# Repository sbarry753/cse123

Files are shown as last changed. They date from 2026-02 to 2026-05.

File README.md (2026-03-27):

# GuSynth – Ultra-Low-Latency Polyphonic Guitar Synth Pedal
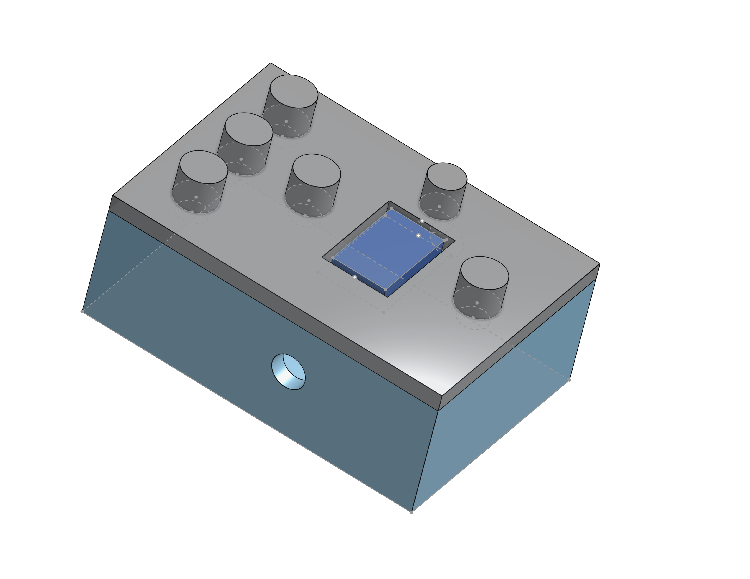
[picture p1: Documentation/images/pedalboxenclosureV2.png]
Aesthetic Prototype

GuSynth is a research + hardware project building a **real-time polyphonic guitar synth pedal** capable of transforming a guitar into other instruments with **ultra-low latency**.

The project combines:

- **Transient-guided neural note detection**
- **Polyphonic inference for guitar input**
- **Direct neural timbre transfer**
- **Embedded deployment on microcontroller hardware**
- **Analog tone shaping and post-processing**

The goal is a **standalone guitar pedal** that lets a guitarist play naturally while hearing the output as another instrument.

---

## Overview

Most pitch detection and guitar synthesis systems rely on longer analysis windows, which adds noticeable delay. GuSynth instead focuses on extracting useful information from the **earliest part of the note**, especially the pick attack, so the system can react quickly enough for live performance.

The project currently explores two connected ML stages:

1. **First neural network:** fast polyphonic note detection from very short windows
2. **Second neural network:** direct timbre transfer from guitar to another instrument

A harmonic LUT-based pipeline and analog processing stages support the overall system.

---

## Signal Path

This is the full signal path of the pedal, from instrument input through conversion, inference/synthesis, and output shaping.

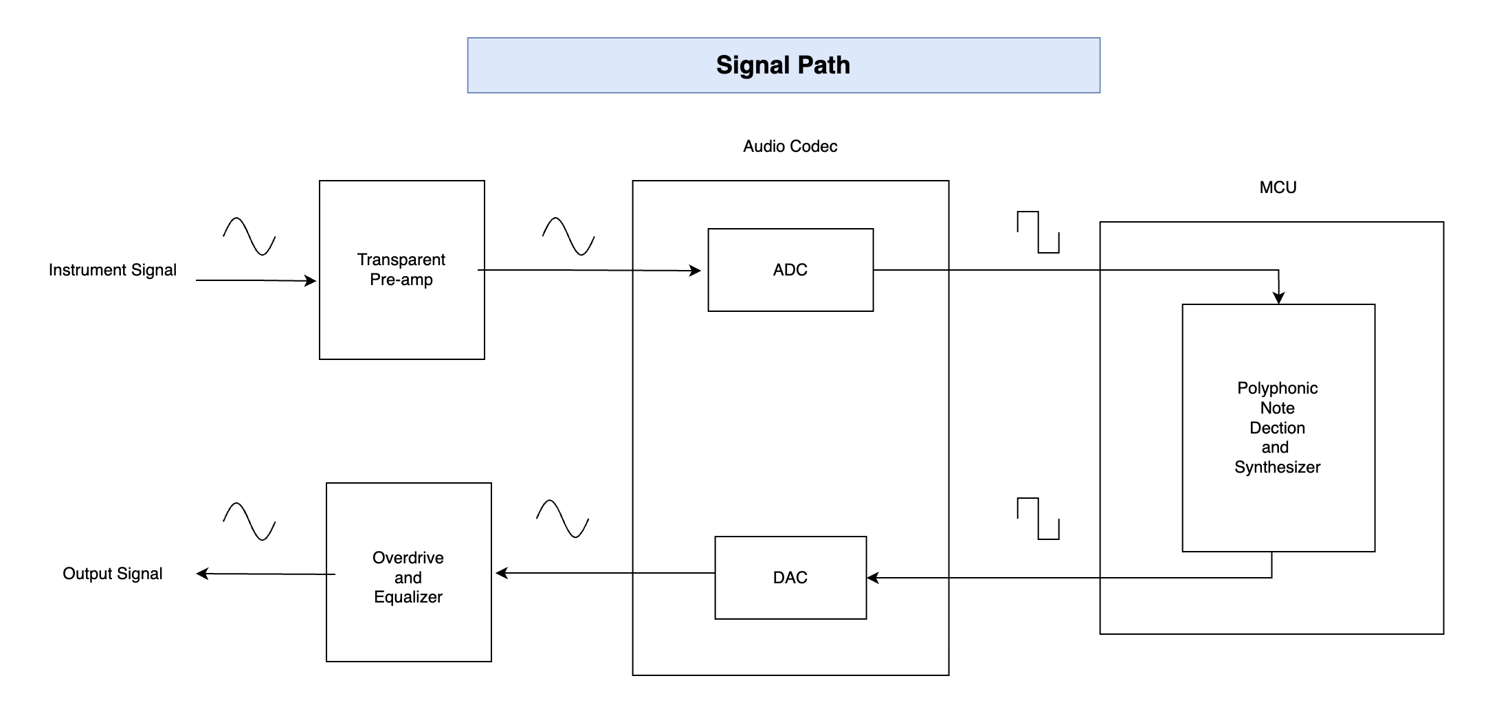
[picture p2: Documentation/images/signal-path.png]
Signal Path


---

## Overall Pedal / System Schematic

This diagram shows the higher-level pedal architecture and how the DSP / neural / synthesis stages connect together.

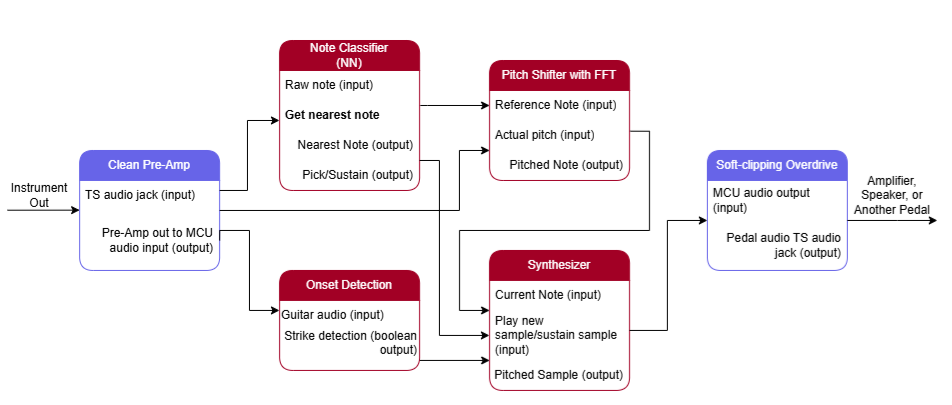
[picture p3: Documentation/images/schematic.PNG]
Overall Schematic


---

## 424 / Analog Circuit Reference

This section documents one of the analog reference directions used in the project for tone shaping / overdrive exploration.

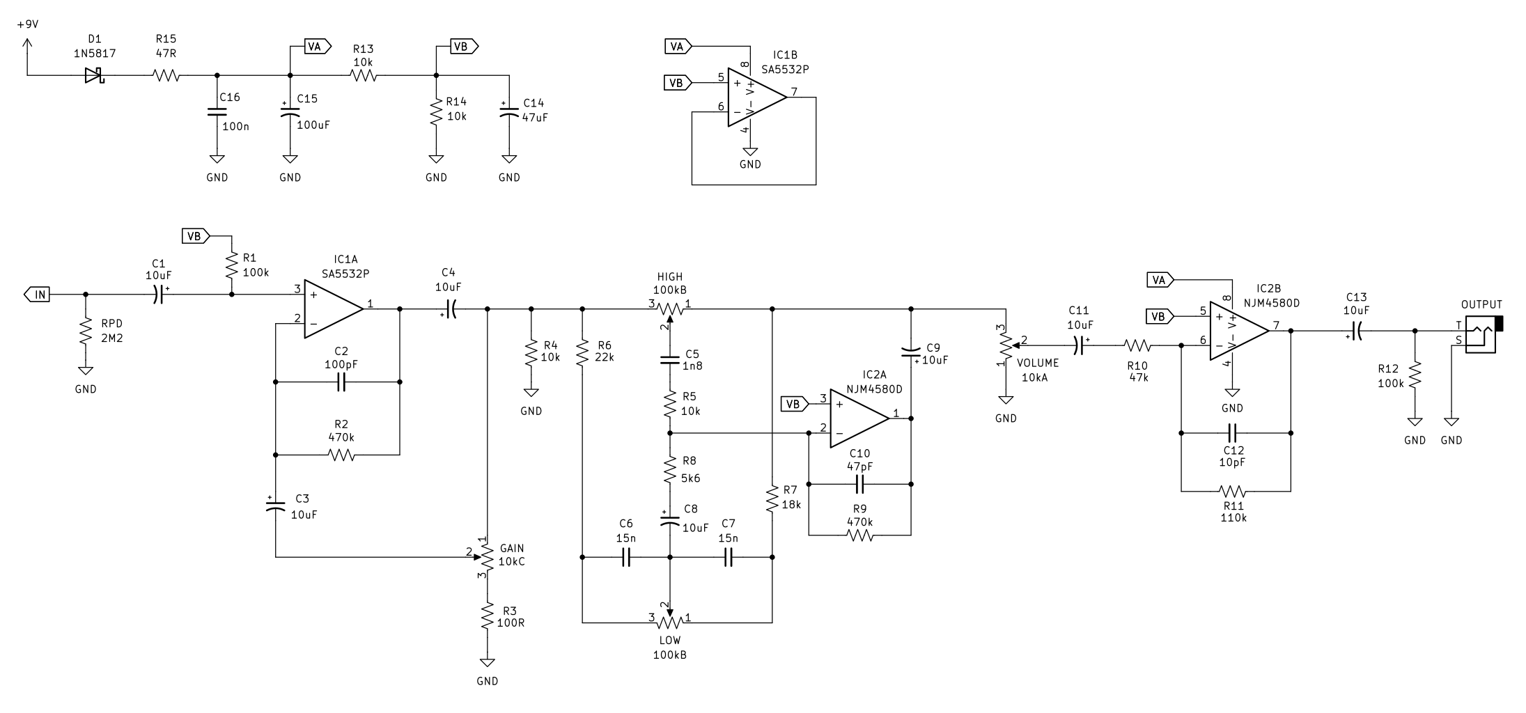
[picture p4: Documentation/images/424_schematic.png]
424 Schematic


---

## Core System Architecture

### 1. First Neural Network – Polyphonic Note Detection

The first model is designed to recognize notes from **very short guitar input windows**, with a strong focus on the **transient / pick attack** region.

It is intended to:

- detect note activity quickly
- work under polyphonic conditions
- provide a MIDI-style or note-based representation
- operate under strict latency constraints suitable for embedded systems

#### Audio Demo – First NN
First NN Input (https://www.youtube.com/watch?v=imzRmc-EM3o)

**After (first NN output / note-detection-driven result):**

First NN MIDI Out (https://www.youtube.com/watch?v=rfo7ya5QwPA)

### 2. Second Neural Network – Timbre Transfer

The second model takes guitar input and transforms it toward the sound of another instrument.

Current work is focused on **guitar → piano-style transfer**, with the long-term goal of supporting more instruments and cleaner real-time conversion.

It is intended to:

- preserve performance timing and expression
- reshape the raw guitar waveform into a target timbre
- run in a streaming low-latency pipeline
- support eventual embedded deployment

#### Video Demo – Second NN

Second NN Out (https://www.youtube.com/watch?v=lIXTaDWCdeU)

## Harmonic LUT Support Pipeline

Alongside the neural models, the project includes a harmonic fingerprint LUT approach used for analysis and refinement.

This system helps by:

- storing harmonic note templates
- comparing incoming spectra to expected note structure
- refining note hypotheses
- supporting interpretable DSP-guided analysis

Rather than treating the project as purely neural or purely classical DSP, GuSynth explores a **hybrid approach**.

---

## Embedded Hardware Target

The long-term target is a compact embedded pedal platform.

### Current embedded direction

- **Daisy Seed / Cortex-M7 class hardware**
- **48 kHz real-time audio**
- small-window streaming inference
- ADC / DAC audio pipeline
- analog front-end and output shaping

### Embedded constraints

- low total latency
- predictable real-time processing
- limited memory / compute budget
- models must be compact enough for sustained streaming

---

## Analog Processing

The pedal is not only digital / ML based. Analog stages are also important for:

- input conditioning
- gain staging
- distortion / overdrive
- EQ shaping
- reducing unpleasant artifacts in synthesized output

This is especially useful when blending guitar and synthetic instrument textures.

---

## Project Status

- ✅ First neural network prototype for transient-guided note detection
- ✅ Second neural network prototype for timbre transfer
- ✅ Harmonic LUT research pipeline
- ✅ System-level pedal architecture defined
- ⚠️ Embedded optimization still in progress
- ⚠️ More training data and refinement needed for cleaner output quality

---

## Repository Layout

- `Documentation/images/`  
  Diagrams, schematics, and system figures

- `Documentation/audio/`  
  WAV demos for model outputs

- `Documentation/video/`  
  Video demonstrations of the system

- `LUT - In Development/`  
  Harmonic fingerprint / template detection work

- `DAISY - In Development/`  
  Embedded hardware and firmware work

- `JUCE - In Development/`  
  Desktop or plugin prototyping

---

## Long-Term Goal

A standalone guitar pedal that:

- detects polyphonic playing with minimal delay
- converts guitar into the sound of other instruments
- runs on embedded hardware
- combines neural models, DSP, and analog circuitry
- remains responsive enough for real live performance

---

## Summary

GuSynth is a hybrid guitar-synthesis system exploring how far real-time note inference and timbre transfer can be pushed under embedded, performance-critical latency constraints.

It is not just a guitar effect — it is an attempt to turn the guitar into a **real-time expressive controller for other instruments**.

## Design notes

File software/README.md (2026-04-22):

#Software

This is where all software related files are going to be listed. Currently, I've moved mine but will be asking if we want to organize our directory through directories. Temporary organizational area for now.

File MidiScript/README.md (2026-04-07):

#MIDI to other instruments
Will be using a python script to convert .midi files into different .wav files with associated instruments.

Current conversion:
.midi to .wav Piano

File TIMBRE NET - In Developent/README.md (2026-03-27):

# DDSP Guitar → Piano (Live Timbre Transfer)

Real-time guitar-to-piano timbre transfer using DDSP (Differentiable Digital Signal Processing).
Designed for live performance with a **<12ms algorithmic latency budget**.

---

## Architecture

```
Guitar audio (256-sample frame, ~5.8ms)
  │
  ▼
Feature Encoder  [~2ms]
  • f0 via YIN autocorrelation
  • RMS loudness in dB
  • MFCC (20 coefficients)
  │
  ▼
MLP Decoder  [~0.5ms]
  • 4-layer MLP, 512 hidden units
  • Trained on YOUR paired data
  • Maps guitar features → piano synth params
  │
  ▼
Additive Synthesizer  [~2.5ms]
  • 64 harmonics + shaped noise
  • Phase-continuous across frames
  │
  ▼
Output audio  [~5.8ms buffer]

Total algorithmic latency: ~11ms ✓
```

---

## Setup

```bash
# 1. Create virtual environment
python -m venv venv
source venv/bin/activate   # Windows: venv\Scripts\activate

# 2. Install dependencies
pip install -r requirements.txt

# 3. On Windows, install ASIO for lowest driver latency:
#    Use ASIO4ALL or your interface's native ASIO driver
```

---

## Prepare Your Data

Organize your paired audio files like this:

```
data/
  guitar/
    phrase_001.wav
    phrase_002.wav
    ...
  piano/
    phrase_001.wav   ← same filename, time-aligned, same duration
    phrase_002.wav
    ...
```

**Requirements:**
- Any sample rate (will be resampled to 44100 Hz)
- WAV or FLAC format
- Files must be time-aligned (same musical content, same duration)
- More data = better results. 10+ minutes of paired audio recommended.

---

## Training

```bash
# Basic training (100 epochs, auto-detects GPU/MPS/CPU)
python train.py --data_dir ./data --epochs 100

# With custom settings
python train.py \
  --data_dir    ./data \
  --epochs      150 \
  --batch_size  128 \       # increase if GPU has memory
  --hidden_size 512 \
  --n_harmonics 64 \
  --lr          3e-4

# Resume from checkpoint
python train.py --data_dir ./data --resume ./checkpoints/epoch_0050.pt
```

Training outputs:
- `checkpoints/best_model.pt` — best checkpoint (use this)
- `checkpoints/model_scripted.pt` — TorchScript export for real-time
- `checkpoints/loss_curves.png` — training curves

**Expected training time:**
| Hardware | ~100 epochs |
|---|---|
| NVIDIA GPU | 20–60 min |
| Apple M-series  | 45–90 min |
| CPU only | 4–8 hours |

---

## Live Performance

```bash
# List available audio devices first
python realtime.py --model ./checkpoints/model_scripted.pt --list-devices

# Run live
python realtime.py --model ./checkpoints/model_scripted.pt

# With settings
python realtime.py \
  --model   ./checkpoints/model_scripted.pt \
  --wet     1.0 \     # 1.0 = full piano, 0.5 = 50/50 blend
  --volume  1.0 \
  --device  cuda      # or mps or cpu
```

**Keyboard controls (while running):**
| Key | Action |
|-----|---|
| `q` | Quit |
| `r` | Reset phase (fix phase artifacts between songs) |
| `+` | Increase volume |
| `-` | Decrease volume |
| `m` | Toggle dry/wet |

---

## Audio Interface Setup

For minimum total latency:

| OS | Driver | Target buffer |
|---|---|---|
| Windows | ASIO | 64–128 samples |
| macOS | CoreAudio | 64–128 samples |
| Linux | JACK | 64–128 samples |

Set `DEVICE_IN` / `DEVICE_OUT` at the top of `realtime.py` to your interface.

```python
# realtime.py — set these:
DEVICE_IN  = "Focusrite USB"     # your interface name (partial match works)
DEVICE_OUT = "Focusrite USB"
```

---

## Troubleshooting

**Model sounds bad / robotic:**
- Train longer (200+ epochs)
- Add more paired data (target >20 min)
- Check that guitar/piano files are actually time-aligned

**Audio dropouts:**
- Increase `BLOCKSIZE` to 512 (adds ~5.8ms latency but more stable)
- Use a dedicated audio interface (not built-in soundcard)
- Close other audio applications

**Phase artifacts between notes:**
- Press `r` to reset phase accumulator
- These are normal for notes with very different f0s

**Latency higher than expected:**
- Run `python realtime.py --model ... --list-devices` and check your interface's native ASIO latency
- Algorithmic latency is fixed at ~11ms; total latency = algorithmic + driver round-trip

---

## File Structure

```
ddsp_guitar2piano/
  model.py       — DDSP architecture (encoder, MLP, synth)
  dataset.py     — Paired audio dataset loader
  losses.py      — Multi-scale spectral loss
  train.py       — Training script
  realtime.py    — Live inference
  requirements.txt
```

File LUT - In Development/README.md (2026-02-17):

# Guitar → Harmonic Fingerprint LUT → Note / Chord Detection (Python prototype for a future JUCE VST)

This repo is a research-stage **template-based pitch / note identification** system for guitar audio.

It builds a **lookup table (LUT)** of *single-note templates* from labeled `.wav` recordings, then:

- **Monophonic:** classifies a single played note by scoring it against every note in the LUT (and every *take* of that note).
- **Polyphonic:** detects multiple notes (like a chord / strum) by fitting the spectrum as a **nonnegative mixture** of note templates (NNLS).

This is not waveform resynthesis. It’s **harmonic-structure matching** in the frequency domain.

---

## What the code actually does

### 1) Build step: multi-take templates per note

For each labeled note recording, the script:

1. Loads the WAV (stereo → mono)
2. Normalizes peak amplitude
3. Extracts a short analysis window (`--start`, `--dur`)
4. Optionally highpass filters (`--highpass`)
5. Computes an FFT magnitude spectrum (Hann by default)
6. For that note’s known fundamental `f0` (from MIDI + A4 reference), measures **harmonic peaks**

For harmonic index `h = 1..K`:

- Look near `h * f0` within `± tol_hz`
- Take the **max magnitude** in that band

That yields a harmonic amplitude vector:

`v = [A1, A2, ..., A_H]`

Then it normalizes it to remove loudness:

`fingerprint = v / sum(v)`

**But** the LUT doesn’t store just the fingerprint — each take stores extra spectral features too:

- harmonic peak frequencies (per harmonic)
- harmonic peak magnitudes (per harmonic)
- harmonic slope (linear fit of `log(amp)` vs harmonic index)
- inharmonicity (average relative deviation from ideal `k*f0`)
- spectral centroid
- spectral rolloff (85%)
- spectral flatness

So the LUT is **multi-take per note**, and each take is a richer “feature snapshot”.

## LUT format (`lut.json`)

Each note entry contains:

- `note`, `midi`, `f0_hz`
- analysis params used at build time (`k`, `tol_hz`, `window`, `analysis_start_sec`, `analysis_dur_sec`)
- `takes[]`: list of per-recording templates
- `source_wavs[]`: which wav files produced the takes

Example (simplified):

```json
{
  "note": "E3",
  "midi": 52,
  "f0_hz": 164.81,
  "k": 60,
  "tol_hz": 15.0,
  "window": "hann",
  "analysis_start_sec": 0.12,
  "analysis_dur_sec": 0.18,
  "takes": [
    {
      "fingerprint": [...],
      "peak_freqs": [...],
      "peak_amps": [...],
      "harm_slope": -0.42,
      "inharm": 0.0031,
      "centroid_hz": 812.4,
      "rolloff_hz": 2490.0,
      "flatness": 0.018
    }
  ],
  "source_wavs": ["samples/E3.wav", "samples/E3_lowstring.wav"]
}
````

---

## 2) Monophonic matching (single note)

Monophonic classification is **not**:

> “extract one fingerprint from the unknown and compare to stored fingerprints”

Instead the code does this:

For **each candidate note** in the LUT:

1. Compute that candidate note’s `f0` from its MIDI (and A4 ref)
2. Compute **live features assuming that f0** (fingerprint + other features)
3. Compare the live features against **every stored take** for that note

### Scoring: cosine similarity + feature penalties

* base similarity: `cosine(fingerprint_live, fingerprint_take)`
* penalties for:

  * inharmonicity difference
  * centroid ratio difference (log)
  * rolloff ratio difference (log)
  * harmonic slope difference
  * flatness difference

Weights are CLI tunable (`--w_inharm`, `--w_centroid`, etc.)

### Multi-take collapse (important)

A note has multiple takes → multiple scores.

Those take scores get collapsed into a **single note score** using:

* `--score_mode max` (default): best take wins
* `--score_mode mean`
* `--score_mode topk --topk N`: average of top N takes

Then the note with the highest final score is your winner.

So the classifier is basically:

> “try every note as if it were correct, see which assumption produces the best harmonic alignment + feature match.”

---

## 3) Polyphonic matching (chords / multi-string)

Polyphonic mode does **not** store chord templates.

It still uses the same **single-note LUT** — but match time changes.

### Step A — prune candidate notes (fast pre-pass)

It runs a cheap fingerprint cosine score per note and keeps only the top `--prune N` notes to limit NNLS size.

### Step B — build FFT-bin templates for each take

For each candidate note and each take:

* Convert the take fingerprint into a **template vector over FFT bins**
* “Paint” a small Gaussian bump at each harmonic frequency
* Weight bumps by the take’s fingerprint values
* Normalize template to unit norm

Optionally it adds detuned template variants (`--detune_cents`, default ±20c) to handle tuning drift.

You end up with a matrix:

`A = [template_1 template_2 ... template_M]`

### Step C — fit the live spectrum as a nonnegative mixture (NNLS)

It computes the live FFT magnitude `y` (optionally `log1p` with `--logmag`), normalizes it, then solves:

`min ||A x - y||  subject to x >= 0`

(using `scipy.optimize.nnls`)

### Step D — collapse templates → notes

Multiple templates correspond to the same note (multiple takes + detunes).

The code collapses them by taking the **max weight per note**, normalizes note strengths by the max, then outputs up to `--max_notes` above `--thresh`.

So polyphonic output is:

> “which notes have strong activations in the NNLS mixture.”

---

## Commands

### Build LUT from explicit labels

```bash
python wav_to_lut.py build --out lut.json --k 60 --tol 15 --start 0.12 --dur 0.18 \
  E3=samples/E3.wav E3=samples/E3_lowstring.wav
```

### Build LUT from a directory (note parsed from filename)

Supports filenames like:

* `E6.wav`
* `F#4_take2.wav`
* `Bb3-clean.wav`
* `E3_lowstring.wav`

```bash
python wav_to_lut.py build_dir --out lut.json --dir samples --k 60 --tol 15 --start 0.12 --dur 0.18
```

### Match monophonic

```bash
python wav_to_lut.py match --lut lut.json --wav unknown.wav --start 0.12 --dur 0.18 --plot
```

Useful knobs:

* `--score_mode max|mean|topk`
* `--w_inharm ...` etc (feature penalty weights)

### Match polyphonic (chord)

```bash
python wav_to_lut.py match_poly --lut lut.json --wav chord.wav --start 0.12 --dur 0.18 \
  --max_notes 6 --thresh 0.25 --prune 60 --detune_cents 20 --logmag --plot
```

---

## Notes / assumptions baked into the approach

* The system **does not do explicit f0 estimation** first.

  * It instead evaluates candidates by “assuming” their f0 and measuring harmonic alignment.
* Short windows matter: `--start` and `--dur` heavily affect stability (attack vs sustain).
* Polyphonic mode is spectrum-mixture-based (NNLS), so it works best when:

  * notes are reasonably harmonic
  * not too much distortion / noise
  * pruning keeps the NNLS problem manageable

---

## Roadmap (VST direction)

This Python code is meant to prototype:

* a note/chord detector that can run on short windows
* multi-take robustness (different strings / pickups / picking styles)
* template-mixture chord inference

A JUCE plugin version would likely need:

* streaming / overlap-add analysis windows
* faster solvers or approximations than full NNLS
* onset (“strike”) detection and tracking across frames

```
```

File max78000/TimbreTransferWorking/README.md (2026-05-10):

# TimbreTranser - MAX78000 FreeRTOS Audio Processing 

## Current functionality
- Audio passthrough, line in/out working on MAX78000FTHR
- FreeRTOS circular buffer integrated and tested
- Has audio processing and buffer demo running simultaneous
- !! NEURAL NETROK INTERFACE PENDING !!

## Hardwware Requirements
- MAX78000FTHR board
- (2) 3.5 mm auxiliary cables
- audio source and audio output device

## Setup development environment

### 1. Update MAX78000 debugger firmware 
 following the instructions [here](https://github.com/analogdevicesinc/MaximAI_Documentation/blob/main/MAX78000_Feather/README.md)

### 2. Install MaxiSDK
- [Install MaximSDK](https://analogdevicesinc.github.io/msdk/USERGUIDE/#installation)
- [setup with Visual Studio Code](https://analogdevicesinc.github.io/msdk/USERGUIDE/#getting-started-with-visual-studio-code)
- Install [Serial Monitor](https://marketplace.visualstudio.com/items?itemName=ms-vscode.vscode-serial-monitor) extension

### 3. **CRITICAL: Replace the MAX9867 driver**
    - Backup `max9867.c/h` in `Libraries/MiscDrivers/CODEC` in the MaximSDK installation folder.
    - Replace `max9867.c/h` with the versions in the `driver` folder contained within *this* folder. Each time we update the driver code, this process must be repeated. (Probably we want to not perform this process later on)

### 4. Build and Flash 
Connect MAX78000FTHR board, and monitor it using the Serial Monitor extension; build and flash using [this](https://analogdevicesinc.github.io/msdk/USERGUIDE/#visual-studio-code) guide.

## Testing Audio Passthrough
1. Connect audio source (computer/phone) → J5 (line-in jack)
2. Connect speaker/headphones → J7 (line-out jack)
3. Play audio - you should hear it through the speaker
4. LED2 should blink at ~1Hz (indicates DMA running)

## Circular Buffer
The project includes a FreeRTOS-compatible circular buffer (`buffer.c`, `buffer.h`) ported from POSIX semaphores written by David Harrison. Demo tasks (producer/consumer) run alongside audio passthrough to verify functionality.
 
## SDK Bugs
1. **Codec driver broken** - Fixed by patched driver (see setup step 3)
2. **I2C not initialized** - Driver assumes I2C already initialized ([Issue #762](https://github.com/analogdevicesinc/msdk/issues/762))

## Debugging in the command line
To step through the program in GDB, follow this sequence:
- Connect the MAX78000FTHR board, and monitor it using the Serial Monitor extension.
- Open a terminal window and enter *this* directory.
- Run `make clean`, then `make all`, then `make flash-hold`.
- Open a new terminal window, without closing the previous one, and enter this directory. In the new terminal window, run `make gdb-debug`. You should now be in GDB, with the program paused at `main()`. [Reference for GDB commands](https://visualgdb.com/gdbreference/commands/)

## Contributors
- Zion - Initial audio passthrough setup
- Yasmeen - Cicular buffer port, SDK bugs, documentation

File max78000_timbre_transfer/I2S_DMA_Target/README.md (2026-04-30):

## Current functionality
At the moment, the program passes audio straight through without affecting it.

## Setup development environment
1. Update MAX78000 debugger firmware by following the instructions [here](https://github.com/analogdevicesinc/MaximAI_Documentation/blob/main/MAX78000_Feather/README.md)
2. [Install MaximSDK](https://analogdevicesinc.github.io/msdk/USERGUIDE/#installation), and [setup with Visual Studio Code](https://analogdevicesinc.github.io/msdk/USERGUIDE/#getting-started-with-visual-studio-code)
3. Install [Serial Monitor](https://marketplace.visualstudio.com/items?itemName=ms-vscode.vscode-serial-monitor) extension
4. Replace the MAX9867 driver
    - Backup `max9867.c/h` in `Libraries/MiscDrivers/CODEC` in the MaximSDK installation folder.
    - Replace `max9867.c/h` with the versions in the `driver` folder contained within *this* folder. Each time we update the driver code, this process must be repeated. (Probably we want to not perform this process later on)
5. Connect MAX78000FTHR board, and monitor it using the Serial Monitor extension; build and flash using [this](https://analogdevicesinc.github.io/msdk/USERGUIDE/#visual-studio-code) guide.

## Debugging in the command line
To step through the program in GDB, follow this sequence:
- Connect the MAX78000FTHR board, and monitor it using the Serial Monitor extension.
- Open a terminal window and enter *this* directory.
- Run `make clean`, then `make all`, then `make flash-hold`.
- Open a new terminal window, without closing the previous one, and enter this directory. In the new terminal window, run `make debug`. You should now be in GDB, with the program paused at `main()`. [Reference for GDB commands](https://visualgdb.com/gdbreference/commands/)

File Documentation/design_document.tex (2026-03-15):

\documentclass[12pt]{article}

\usepackage{hyperref}
\usepackage{amsmath}
\usepackage{enumitem}
\usepackage{graphicx}
\usepackage{eso-pic}
\usepackage{float}

\title{
\textbf{GuSynth: The Polyphonic Guitar Synth Pedal}\\
\vspace{0.5em}
\large System Overview and Design Description}

\author{Team 2: Kai, Zion, Barry, Nick, Yasmeen, Aaryan}

\begin{document}

\AddToShipoutPictureBG*{%
    \AtPageLowerLeft{%
        \hspace{1cm}% left margin from edge
        \raisebox{1cm}{% height from bottom
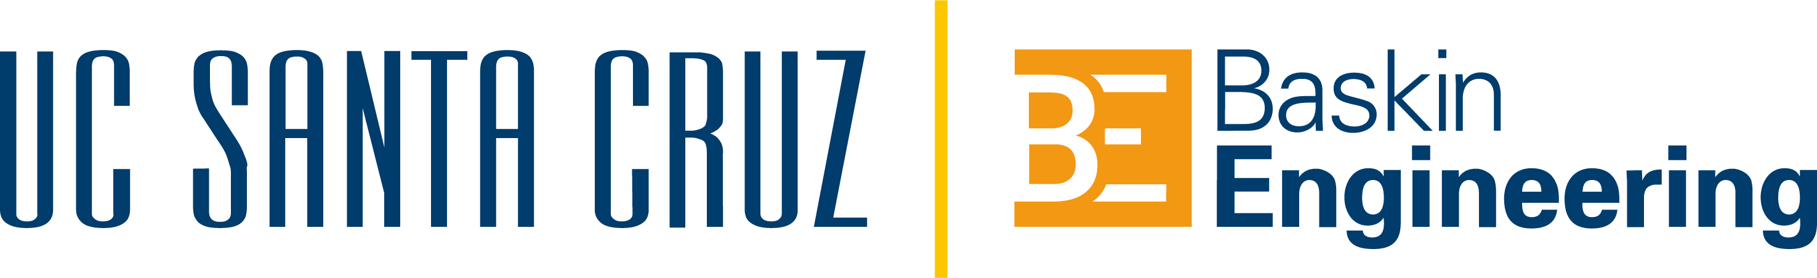
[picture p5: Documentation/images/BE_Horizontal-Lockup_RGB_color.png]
            
        }
    }
}
\maketitle
\thispagestyle{empty}

\newpage
\tableofcontents  
\newpage

\newpage

\section*{Executive Summary}
This project explores the design of a guitar pedal that transforms traditional guitar sounds into tones resembling other instruments or synthesizers. Using a mixture of both analog and digital effects, this system aims to form a physical guitar pedal that combines multiple systems to achieve this. One of the biggest constraints to consider is latency; the system should produce the output sound fast enough to feel immediate during play.

\section{Introduction}
\subsection{Need and Goal Statements}
\textbf{Need Statement:} Guitarists want to be able to create the sound of another instrument without having to remove their guitar during live performance, or learn a new instrument.\\
\textbf{Goal Statement:} Allow guitarists to play the sounds of different instruments with their guitar in real time.

%old statements
%\textbf{Need Statement:} Existing guitar-controlled synthesizers cannot detect and play more than one note at once, which limits the expressiveness of the guitar.\\
%\textbf{Goal Statement:} Design a polyphonic guitar synth pedal that is intuitive for guitarists and suitable for live performance. 
%(ALLOW MUSICIANS TO PLAY DIFFERENT SOUNDS WITHOUT SWITCHING INSTRUMENTS IN REAL TIME (<10 ms))

\subsection{Design Objectives} %(Polyphonic is the objective/solution)

\begin{enumerate}[label=(\alph*)]

    \item \textbf{Polyphonic Note Detection} \\
    The guitar is inherently polyphonic, but accurate and general-purpose polyphonic note detection is still an open challenge. In order to provide accurate polyphonic note detection, the device needs to accurately infer the number of distinct notes played in a guitar chord, and their individual pitches.

    \item \textbf{Low Latency} \\
    A latency of $10\,\text{ms}$ is targeted, to facilitate an intuitive and enjoyable user experience. The player should not perceive any delay between playing a note and hearing the synthesized sound through their amplifier. This strict latency requirement drives many of our architectural and algorithmic decisions.

    \item \textbf{Form factor} \\
    The device must fit comfortably onto a guitar pedal board, and conform to the design language of existing guitar effects pedals. Additionally, the device must accept 9V DC power from a coaxial jack (5.5mm x 2.1mm, center-negative), standard for guitar pedals.

%    Note: By existing design language, I mean:\\
%    - Input goes from right to left \\
%    - Power jack is facing away from user \\
%    - All user controls located on the upward-face of the pedal\\
%    - Bypass footswitch is located on lower portion of the interface\\
%    - Knobs and parameter controls are located on the upper portion of the interface\\
%   Where should this information go?

\end{enumerate}

%\subsection{Existing Products}
% other guitar synth pedals (BOSS GT-3, 1997, has a monophonic guitar synth effect)
% melodyne and other software solutions (polyphonic detection)

\subsection{Target Audience (Personas)}
\begin{enumerate}[label=(\alph*)]
  \item \textbf{Bedroom Guitarist} \\
  A casual hobbyist looking to expand their creative palette without investing in additional instruments. They want expressive, unique sounds from gear they already own, in a package that is easy to set up and experiment with.
  \item \textbf{Recording Studio} \\
  A producer or session musician seeking precise, repeatable tones for tracking  and layering. They value low noise, consistent output, and seamless integration  into an existing signal chain or Digital Audio Workstation (DAW) workflow.
  \item \textbf{Live Performer} \\
  A performing musician who needs reliable, low-latency response under stage  conditions. They prioritize a rugged form factor, intuitive controls that can  be adjusted on the fly, and a sound that cuts through in a live mix.

\end{enumerate}

\clearpage
\section{Design of the Pedal}

\subsection*{Aesthetic Prototype}
\begin{figure}[H]
    \centering
    
    \caption{Aesthetic Prototype}
    \label{fig:aesthetic-prototype}
\end{figure}

\subsection*{High-Level Block Diagrams}

\begin{figure}[H]
    \centering
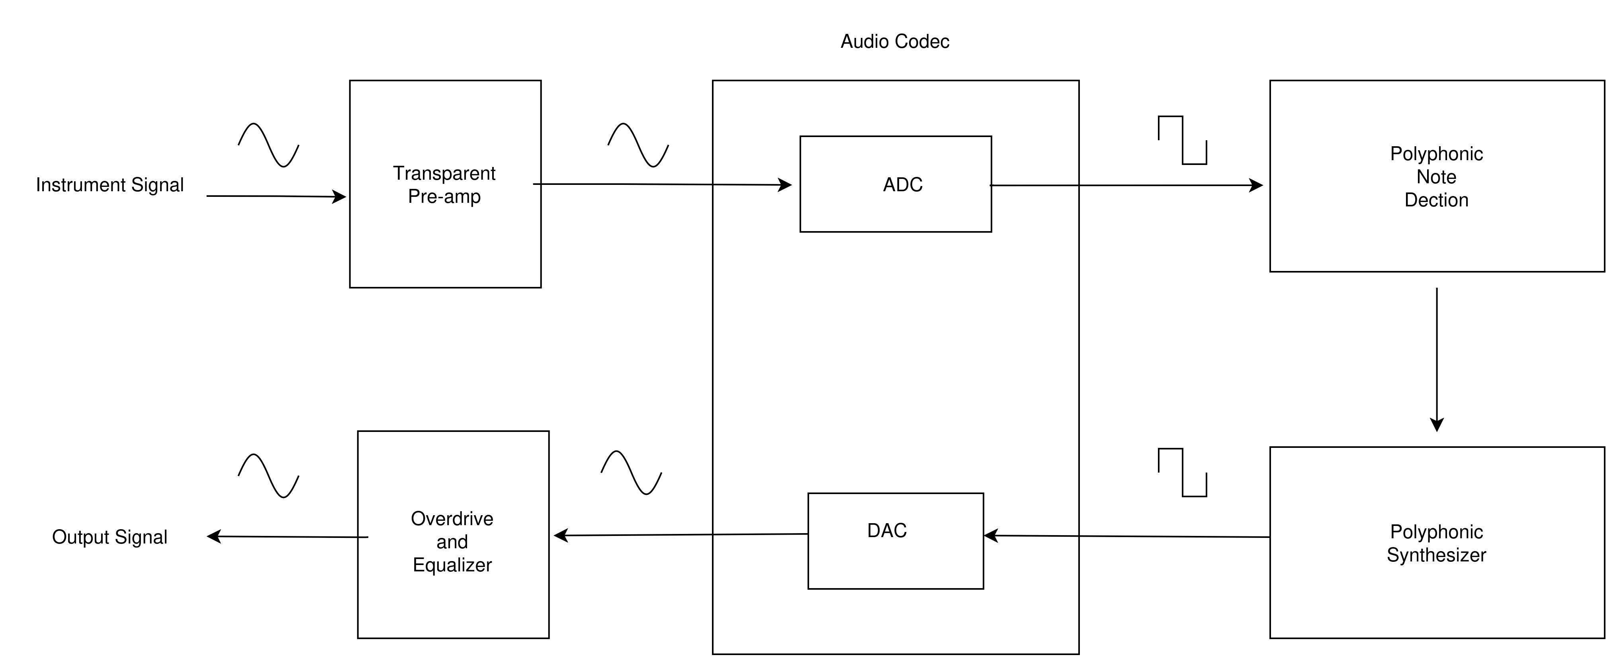
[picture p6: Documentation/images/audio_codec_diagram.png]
    
    \caption{Signal Path }
    \label{fig:block-diagram-signal}
\end{figure}

\begin{figure}[H]
    \centering
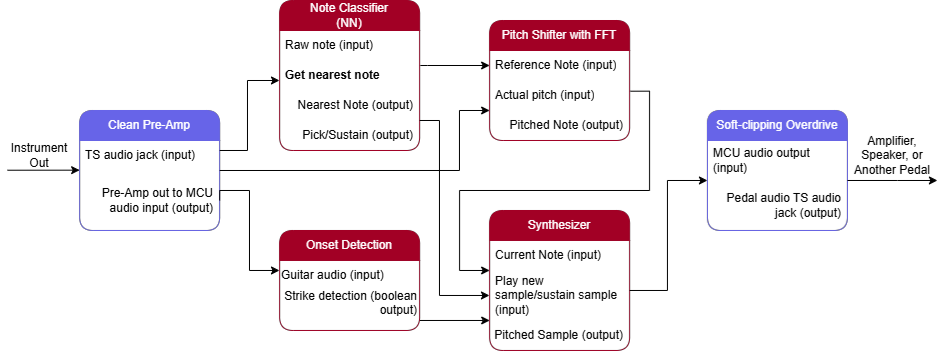
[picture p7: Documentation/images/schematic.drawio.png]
    
    \caption{Pedal Block Diagram}
    \label{fig:block-diagram}
\end{figure}

\subsection{Software System}

The software pipeline begins when the micro controller receives a digitized audio  stream from the analog-to-digital converter (ADC). The incoming samples are written into a ring buffer, which alternates between two fixed-size memory regions.  While one buffer accumulates new input samples, the other is made available for processing. This scheme ensures continuous, uninterrupted audio throughput and is  fundamental to meeting the low-latency requirements of the system.

Once a buffer is released for processing, the audio data is passed into a neural network inference pipeline. Rather than performing an explicit frequency decomposition,  the network approximates the pitch and onset characteristics of the incoming signal  directly, identifying which notes are present in the input. The microcontroller then uses these predictions to drive a synthesis engine, which generates an output waveform to produce the desired sound effect. The synthesized digital signal is subsequently converted back to an analog output via the digital-to-analog converter (DAC), where it is routed into the analog output stage.

\subsubsection{Neural Network}
A neural network is used to perform rapid note detection from the incoming guitar signal. Traditional pitch detection methods require observing multiple waveform periods, which introduces latency that is too high for a real-time pedal. Instead, a small neural network analyzes short audio windows (approximately 5–8 ms) to infer note identity directly from the signal’s transient and early harmonic content.
The model is implemented as a lightweight 1-D convolutional neural network designed for embedded inference. It predicts note class and onset information from each audio window, allowing the system to detect new notes almost immediately after a string is picked. These predictions provide an early estimate of the notes present in the signal, which can then be refined by later stages of the detection pipeline.

The trained network is exported to C and compiled directly into the microcontroller firmware, allowing it to run efficiently within the real-time audio processing loop. This approach enables low-latency note detection suitable for live instrument synthesis.
\subsubsection{Synthesizer}

The microcontroller supports any mathematically programmable audio effect, with the available effects limited only by the memory constraints of the hardware. Each effect is implemented as an independent processing function that transforms the incoming audio sample using a defined algorithm. The baseline implementation includes fuzz and distortion, which shape the waveform through non-linear gain functions. The firmware architecture allows developers to implement additional effects during the build phase, provided they can be expressed as a deterministic sample-by-sample transformation and fit within the available memory budget of the microcontroller. Once the effect is applied, the processed signal is passed through an automatic gain control (AGC) stage, which normalizes the output volume before the signal is forwarded to the DAC.

\subsection{Embedded Platform}
The embedded system bridges the digital and analog components of the pedal. The guitar signal from the transparent preamp enters an audio codec. The audio codec converts the analog waveform into discrete digital samples via an Analog-to-Digital converter. Then, these samples are transferred to the microcontroller using the Serial Audio Interface (SAI). Transferring the audio samples to the MCU is performed using Direct Memory Access (DMA). DMA places data into the MCU's RAM without CPU intervention, removing the need for the CPU to constantly poll and waste cycles. Once the samples are in RAM, the polyphonic and algorithms process the audio in software. When the signal has finished processing, it is sent back to the audio codec via DMA, then the Digital-to-Audio converter (DAC), and finally into the analog stage.

Audio is processed in small blocks to maintain our $<10\,\text{ms}$ latency target. Each stage in this pipeline is designed with real-time performance in mind. Furthermore, the pedal will feature a digital OLED screen. The screen indicates the current selected synth type. To change the currently selected synth and cycle through all options, a button is used. The OLED screen and the microcontroller communicate via the I2C protocol.

\subsection{Analog Circuits}
The pedal contains two primary analog circuits.

\subsubsection*{Transparent Preamp}
The preamp boosts the guitar signal to line level before feeding it into the ADC of the microcontroller. It is designed to be transparent so that the note detection neural network, which is trained on DI guitar audio, can work effectively.

\subsubsection*{Overdrive Circuit}

\begin{figure}[H]
    \centering
    
    \caption{Overdrive and Equalizer Circuit Schematic}
    \label{fig:424-schematic}
\end{figure}

The DAC of the microcontroller then feeds the synthesized audio signal into the second analog stage. This second stage is an overdrive circuit with EQ controls. This allows us to shape the tone and gain of the synth in the analog domain before sending it to the user’s amplifier, pedal chain, or other compatible equipment. This stage also provides master volume control.

Our current prototype draws inspiration from the Tascam 424 preamp architecture and a simple Wampler-style overdrive circuit. 

\subsection{Physical Construction}
The pedal enclosure follows the mechanical design conventions of standard guitar effects pedals in order to integrate easily into existing pedalboards.
The user interface consists of two rotary knobs, a push button for switching between synthesizer modes, and a foot-actuated bypass switch. The knobs are panel-mounted potentiometers connected to the microcontroller’s ADC inputs, allowing the user to adjust effect intensity and select different synthesis modes. The footswitch is designed for repeated mechanical stress during live performance.
A small OLED display is mounted on the top panel of the enclosure to provide feedback about the currently selected synthesizer mode. This allows the user to quickly verify which sound is active without relying solely on knob positions.
\section{Evaluation}
Evaluation of the pedal focuses on verifying that the system meets its functional requirements and performance goals. The evaluation process examines both hardware reliability and system performance, including power behavior, mechanical durability, and audio latency.

Testing procedures were designed to validate the pedal under realistic usage conditions similar to those encountered by musicians during rehearsal, recording, and live performance. These tests ensure that the device behaves predictably when subjected to typical physical interaction.

The evaluation phase also helps identify potential areas for improvement in the design, such as latency optimization, mechanical durability, or signal quality. By systematically verifying the core requirements of the system, we can properly determine that our prototype reaches our desired goals.
\subsection{Functional Prototype}

% Tests verify whether the design objectives are met
% Need to test every configuration
\subsection{Testing} 

\subsubsection{Power on}

\textit{Summary: The pedal should only power on when an input cable is connected. The power LED should only illuminate when the effect is not bypassed.}\\

Procedure:
\begin{enumerate}
    \item Initially, the pedal has no power or signal connections.
    \item Connect the pedal to a 9V DC, center-negative power supply.
    \item \textbf{Check}: The power LED should be off.
    \item Press the bypass switch.
    \item \textbf{Check}: The power LED should be off.
    \item Connect the output cable from the pedal to a powered-on guitar amplifier.
    \item \textbf{Check}: The power LED should be off.
    \item Connect the input cable.
    \item If the power LED is off, press the bypass switch.
    \item \textbf{Check}: The power LED should be illuminated, and the effect should be active.
    \item Disconnect the input cable.
    \item \textbf{Check}: The power LED should be off.
    \item Reconnect the input cable.
    \item \textbf{Check}: The power LED should be illuminated and the effect should be active.
    \item Press the bypass switch.
    \item \textbf{Check}: The power LED should be off and the unaltered guitar signal is passed to the amplifier.
\end{enumerate}
\subsubsection{Physical construction}

\textit{Summary: The pedal should support the full weight of an adult (max. 220lbs).}\\

Procedure:
\begin{enumerate}
    \item Place a flat, broad wooden platform onto the bypass switch.
    \item Load the platform with 220lbs of weight, taking care that it is supported entirely by the bypass switch.
    \item Remove the load, then the platform.
    \item \textbf{Check:} The pedal is not damaged or deformed in any way.
    \item \textbf{Check:} The bypass switch still toggles the effect.
\end{enumerate}

\subsubsection{Latency}
% This should be made more specific, and may need an illustration, but this is the idea.
\textit{Summary: The pedal must have a latency under 10ms.}\\\\
Equipment:
\begin{itemize}
    \item Oscilloscope
    \item Function generator
    \item 1/4" TS instrument cable x 2
    \item 1/4" TS jack, female x 2
\end{itemize}
Procedure:
\begin{enumerate}
    \item Configure the function generator to send a 440Hz, 100mVpp sinusoidal wave into a 1/4" TS jack.
    \item Channel 1 of the oscilloscope reads the output of the function generator from the 1/4" TS jack.
    \item A 1/4" instrument cable connects the output of the function generator to the input of the pedal.
    \item A 1/4" instrument cable connects the output of the pedal to the other 1/4" TS jack.
    \item Channel 2 of the oscilloscope reads the output of the pedal from the 1/4" TS jack.
    \item Configure the oscilloscope to simultaneously display Channel 1 and 2, with the same time scale.
    \item \textbf{Check:} Use cursors or other utilities on the oscilloscope to determine the phase shift of the waveform introduced by the pedal. If the pedal introduces a 10ms delay or higher, this test is failed.
\end{enumerate}

%------------------------------------------------
\section*{Appendix 1: Problem Formulation}
\subsection*{Conceptualizations}
The core concept of this project is a guitar pedal capable of transforming the sound of a guitar into the timbre of other instruments or synthesized sounds in real time. Unlike traditional guitar effects pedals that modify the waveform of the input signal directly, this system attempts to infer the musical notes being played and then generate a new signal based on those notes.

The final concept combines multiple techniques. A neural network is used to estimate note activity from very short audio windows, while a digital synthesis engine generates the output sound. Analog circuitry is used both before and after the digital processing stage to condition the signal and shape the tone.

This hybrid approach allows the system to maintain low latency while still enabling expressive sound transformations.
\subsection*{Brainstorming}
During the brainstorming phase, the team explored multiple possible features and system architectures for the pedal. Ideas included:

\begin{itemize}
\item Real-time instrument emulation (piano, strings, brass)
\item Guitar-to-MIDI conversion
\item Polyphonic pitch tracking
\item Neural network–based note detection
\item Analog distortion and tone shaping
\item Built-in effects such as fuzz or modulation
\item Visual feedback through an OLED display
\item Adjustable synthesis parameters through knobs
\item Pedalboard-compatible enclosure design
\end{itemize}

\subsection*{Decision Tables}
During the design process, several alternative approaches were evaluated. Table~\ref{tab:decision} summarizes the major design choices and the reasoning behind the final selections.

\begin{table}[H]
\centering
\resizebox{\textwidth}{!}{
\begin{tabular}{|l|l|l|l|l|}
\hline
Design Component & Option A & Option B & Option C & Selected Approach \\ \hline
Pitch Detection & FFT peak detection & Autocorrelation/YIN & Neural network & Neural network \\ \hline
Signal Processing & Fully analog & Hybrid analog/digital & Fully digital & Hybrid analog/digital \\ \hline
Synthesis Method & Sample playback & DSP synthesis & External MIDI synth & DSP synthesis \\ \hline
Display Interface & No display & LED indicators & OLED display & OLED display \\ \hline
Control Interface & Buttons only & Knobs only & Knobs + button & Knobs + button \\ \hline
\end{tabular}
}
\caption{Design decision comparison}
\label{tab:decision}
\end{table}
The neural network approach was selected because it offers the potential for lower latency detection compared to traditional pitch detection methods, particularly when analyzing short windows of audio.

\subsection*{Morphological Charts}
A morphological chart was used to explore combinations of possible subsystem implementations.

\begin{table}[H]
\centering
\begin{tabular}{|l|l|l|l|l|}
\hline
Component & A & B & C & Selected \\ \hline
Pitch Detect & FFT & YIN & NN & NN \\ \hline
Processing & Analog & Hybrid & Digital & Hybrid \\ \hline
Synthesis & Samples & DSP & MIDI & DSP \\ \hline
Display & None & LEDs & OLED & OLED \\ \hline
Controls & Buttons & Knobs & Knobs+Btn & Knobs+Btn \\ \hline
\end{tabular}
\caption{Design decision comparison}
\end{table}
%------------------------------------------------

\clearpage
\section*{Appendix 2: Planning}

\subsection*{Basic Plan / Gantt Chart}

\begin{figure}[H]
    \centering
    
    \caption{Winter Quarter Gantt Chart}
    \label{fig:wintergantt}
\end{figure}

\subsection*{Division of labor during prototyping phase}
This graph is a screenshot from our GitHub Project of tasks assigned, in progress, on the backlog and completed grouped by our team members. The pink columns are what you're looking for, they are the completed tasks done by each member. 
Kai: Kaimul24
Nick: NickWeaver02
Aaryan: aaryanhlawat
Barry: sbarry753
Yasmeen: yamaniiiii
Zion: zion-silveyra
\begin{figure}[H]
    \centering
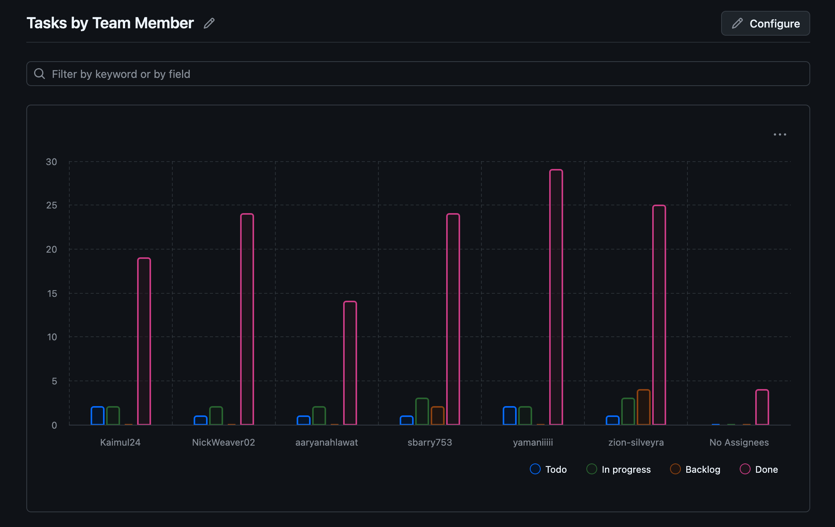
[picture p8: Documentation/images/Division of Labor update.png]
    
    \caption{Division of Labor}
    \label{fig:labor}
\end{figure}

\subsection*{Collaboration ( did you use tools beyond your repository? how did you assign tasks? )}
We use a GitHub Project that ties into our repository. There are a lot of tasks that are not necessarily able to be uploaded to a repository so we use the GitHub Project to track our members' progress on those.  

At the beginning, we used a Google Drive folder for collaboration on written assignments. We have since ported those documents to our repository, but we still use the Google Drive folder to organize collaborative files, like the Draw.io file for the overhead schematic, before pushing them to GitHub.

This design document is made with Overleaf, which is an online LaTeX editor that has collaborative functions like Google Docs. We then upload this work to our GitHub repository.

We communicate daily using our Discord server and have our discussions separated simply into a few channels: general, links and images, analog, embedded, and software. This helps us keep our communication organized and share our progress and findings.

We use Onshape, a collaborative cloud based CAD suite, to create our aesthetic prototype. There is a revision system included in Onshape. Our designs are then pushed to our GitHub repository.

We use Canva for making our demo slides. Canva is a collaborative cloud based graphic design suite that is easy to use. We push updated versions of our slides to our GitHub repository.

%------------------------------------------------
\section*{Appendix 3: Test Plan and Results}

\subsection*{Analog Effect Behavior}
We set out to make a distortion effect for the analog effect portion of the pedal. In order to test whether our distortion effect actually distorts the guitar signal we hooked up our circuit to an oscilloscope and a signal generator. The signal generator is generating a sine wave at 440Hz at 90mVpp to provide a clean A note from a guitar, the yellow wave. We're looking for the guitar's signal to clip at the peaks of the wave. The blue wave is the output from the distortion effect and it is clearly clipping the peaks of the signal and turning the guitar's sine wave into almost a pure square wave. This is the behavior of a hard clipping fuzz distortion effect which is the exact effect tested here.
\begin{figure}[H]
    \centering
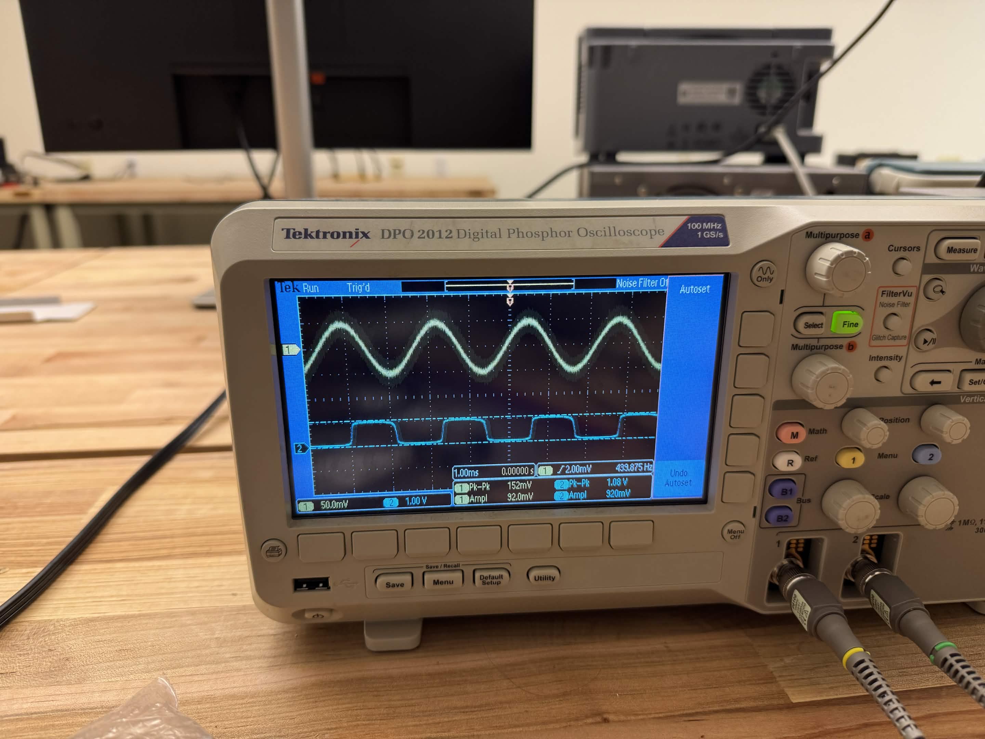
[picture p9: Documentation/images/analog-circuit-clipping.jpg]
    
    \caption{Clipping Distortion of an Analog Signal}
    \label{fig:analogclippig}
\end{figure}

\subsection*{Daisy Seed Benchmarking}
To get a sense of the processing power of the Daisy Seed (ARM Cortex M7 CPU), we decided to run a series of benchmarks. We first ran benchmarks for standard audio effects, similar to those found in the DaisyExamples repository provided by Electrosmith. In those tests, we determined that the actual audio effects did not result in any significant CPU load within a time budget. Then, we decided to stress test the MCU with matrix multiplication. This was an important benchmark to run because it is computationally demanding and relates directly to neural network inference performance. However, we found the MCU performed relatively poor in matrix multiplication, unaligned with real-time inference in mind. The MCU hit its maximum CPU load quickly during matrix multiplication, despite optimizations.

More detailed benchmarking information can be found in the \textit{Benchmarking} directory of our repository.

\begin{figure}[H]
    \centering
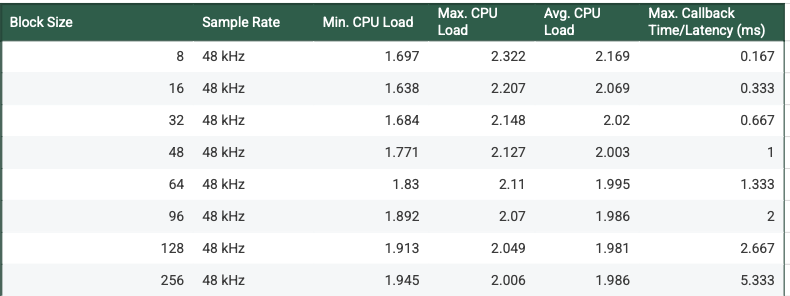
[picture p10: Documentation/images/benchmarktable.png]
    
    \caption{Benchmark Table (Passthrough)}
    \label{fig:benchmarkchart}
\end{figure}

\begin{figure}
    \centering
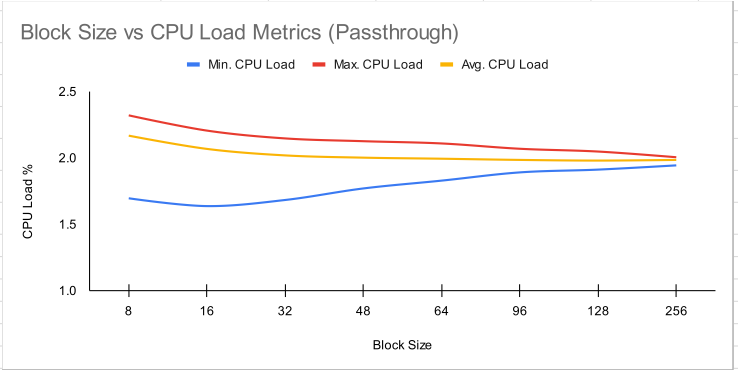
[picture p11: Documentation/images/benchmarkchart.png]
    
    \caption{Benchmark Chart (Passthrough)}
    \label{fig:benchmarkchart}
\end{figure}

%------------------------------------------------
\section*{Appendix 4: Review}

\subsection*{Kai}
For this quarter, I believe we should be proud of what we have accomplished this far. As someone who has had no prior experience with guitars or music creation, this project has allowed me to learn something new. I also really enjoy the direction this project is taking. Running neural network inference on a microcontroller has been something I've been wanting to do for a while, I just didn't come up with a project I really liked. 

If I were to start this project over again, I would like to have started with a more powerful microcontroller. While the Daisy Seed is meant for high-quality audio systems, it doesn't have nearly enough processing power for real-time neural network inference as our project currently stands. Running the matrix multiplications benchmarks revealed the computational limitations of the Daisy Seed. The Teensy 4.0 we were considering (but shipping was delayed) using is faster, but it still uses the same CPU. Early next quarter, we can still try to optimize inference on the Daisy Seed (continue working with tflite micro), but it may be worthwhile to consider more powerful MCU options.

\subsection*{Zion}
I'm very happy with the progress we've made this quarter. Initially, I had pitched the idea of making a digital multieffects unit for guitar, but the project has been going in a far more interesting direction since we've adjusted our goal. I've been able to use this project as an opportunity to learn about audio circuits, which has been wonderful. I am excited that next quarter we will try and design a PCB for our project.

If I were to start this project over again, I would spend more time researching relevant papers and existing tools, and sharing findings with the team. I found an optimizing compiler for neural networks targeting STM32 microcontrollers (STEDGEAI-CUBEAI) rather late in the quarter. Had I found this earlier, our team could have saved a lot of effort. I would also have spent more time documenting the work I had completed. Most of the work I had done researching analog effect circuits, constructing the overdrive/EQ circuit, and learning to use KiCad appears invisible in our repository. 

\subsection*{Barry}
What went well was that I learned a lot about guitar pedal design which is something that I've been wanting to do for many years now. We figured out which type of effect we wanted for the analog circuit pretty quickly and ordered parts immediately. The Daisy Seed microcontroller we were planning to use arrived very quickly and we found out that our backup, the Teensy 4.0 coming from Adafruit, took weeks for parts to arrive. I discovered a local guitar shop that stocks a few very common pedal parts too. Finding DIY pedal hobbyist sites online was very easy. There are a lot of passionate people out there that I'm thankful for their guidance and their fast shipping. Zion has lent me a guitar so I've been trying to learn guitar so that we can easily test our pedal design. Half our team has a guitar and the other half has a Daisy Seed/Pod so we all can test our designs. We frequently meet up in person to complete work and I enjoy every moment of it. I've also learned to use Github Project and find it very useful for keeping track of all our tasks and looking at the Roadmap. Making the CAD model for our aesthetic prototype was a breeze because of my previous CAD experience but I did have to learn a new CAD suite, Onshape.

Our team formed at the last week that we could form teams and we took a while to decide on a project to move forward with. And then it took us a while to figure out what we wanted the pedal to actually do. I wish I had joined this team earlier so that we could have made these decisions earlier. I still think that we've done a bang-up job despite our shorter timeline for this quarter. I also wished that I had ordered a bunch more parts for different types of analog circuits. We were lucky that I had a bunch of parts already at my disposal from previous personal projects. But I didn't have a bunch of film capacitors or large logarithmic potentiometers or other common pedal parts. We have the luxury of money but not the luxury of time, so I put in a few rush orders. I wish that I had sourced a bunch of those earlier on because we found out that we didn't particularly like the sound of the initial simple overdrive pedal we made and instead loved the simple fuzz we made a lot later in the quarter. I did take a number of photos and videos of our pedal design and testing days and would put them in our shared Discord server. The issue with that is that it's not our GitHub so going forward I will keep in mind that if it's not on the GitHub and in main then it doesn't really exist.

\subsection*{Nick}
For my portion of the project, I focused on developing the neural network used for early note detection in the audio pipeline. One aspect that went well was successfully training a lightweight model capable of analyzing very short audio windows (around a few milliseconds) and producing predictions about note identity and onsets. This demonstrated that a neural approach could detect useful musical information even before the harmonic structure of a note is fully established, which is important for keeping latency low in a real-time pedal system. Through this process I also built the dataset generation and training pipeline, which involved labeling attack and sustain regions in recorded guitar samples and applying data augmentation to make the model more robust to variations in gain and noise.

However, one challenge I encountered was realizing how computationally heavy polyphonic detection becomes when attempting to run the full system in real time on embedded hardware. While the neural network itself can be made relatively small, combining it with polyphonic spectral solvers and real-time audio constraints adds significant complexity and processing cost. If I were to approach this project again, I would likely explore ways to simplify the detection problem or shift the role of the neural model. One idea would be to use the system primarily as a data-generation and labeling tool to build a large dataset of guitar sounds, which could then be used to train a guitar “voice changer” style model that transforms the input signal into a synthesized sound directly. This approach might avoid the need for explicit real-time polyphonic note detection while still achieving expressive instrument-style synthesis.

\subsection*{Yasmeen}
The design process went well for our team and it has been a great learning experience for me. I am happy with how I approached the testing at the beginning with simple passthrough tests to verify signal chain. Building up the documentation and demo materials has been valuable in explaining our system to others, and in turn pushed me to understand better how all the pieces connect. I am proud that I stayed on top of updating the project git repository, this helped collaboration run smoothly. If I could do this all over again, I would document even more, my handwritten notes are scattered across different notebooks and I could have kept them more organized. I also would try to get more invloved with the software side of things so I could have better integrated it with embedded. 

\subsection*{Aaryan}
A major success of this project was bridging the gap between abstract software math and real-world analog hardware. While I contributed heavily to the DSP architecture for the Daisy Seed, optimizing real-time waveshaping algorithms like Fuzz, Distortion, and Wavefolding for an embedded ARM processor, the biggest takeaway was stepping entirely outside my comfort zone. Having never worked with music technology before, learning the fundamentals of guitars, notes, and audio signal processing was incredibly eye-opening and instrumental to my success on the software side. Ultimately, what made this all come together was our team's communication and collaboration. They created a fun, supportive environment, patiently taught me the musical and hardware concepts I was unfamiliar with, and turned a steep learning curve into an incredibly rewarding experience.

On the flip side, for us, a major learning experience was the initial scoping and design phase. Because we were all so eager to dive into the project, our shared vision naturally evolved as we worked, which led to a few normal pivots and iterations along the way. While iterating is a natural part of any complex engineering project, dedicating a bit more time upfront to lock in a unified roadmap together would have really streamlined our early development. Beyond the team's planning phase, I also realized I needed to brush up on my own technical readiness. I ended up spending valuable project time relearning several core DSP algorithms from my prior coursework that I hadn't used in a while. Moving forward, balancing thorough project mapping with a quick review of foundational theory before jumping into the code will definitely be a priority for me.

\end{document}

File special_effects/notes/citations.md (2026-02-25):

#Citations

https://forum.kemper-amps.com/forum/thread/26817-a-dry-guitar-track-for-our-tests - Provides free, dry, guitar track

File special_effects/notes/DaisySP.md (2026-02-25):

#Notes on DaisySP module

The arm-none-eabi-gcc tool-chain must be installed.

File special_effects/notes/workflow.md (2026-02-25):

#Workflow

Will be operating in C.

1) Download clean .wav files with guitar samples
2) Write C++ audio to test .wav implemntation
3) Process audio using DaisySP
4) Export .wav file

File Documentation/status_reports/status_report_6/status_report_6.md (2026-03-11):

# Status Report 6

**Authors:** Yasmeen Amani, Zion, Kai, Barry, Nick, Aaryan

**Date:** March 2026

---

## Collaboration System Links

Github: https://github.com/sbarry753/cse123

---

## Current Personas + Clientele

People who play guitar and want to expand the tonal capabilities of their instrument.

Current Need Statement
"Articulate the need as an expression of dissatisfaction with the current situation"

A guitar only makes a guitar sound, and not the sound of other instruments or synthesizers. A musician may have developed intuitive control of the guitar, but cannot easily transfer it to a keyboard or other instrument.

---

## Current Goal Statement

"A brief, general, and ideal response to the need statement"

Design an enviable guitar pedal that detects the notes a guitarist is playing, and plays the same notes through a digital synthesizer.

---

## Decisions Made This Week

- We came up with the foundations of our testing and documentation, as well as understand the whole requirements of what we need to show for our deliverables at the end of the quarter.
- Decided on OLED Screen for prototype display.
- Using Onshape to design pedal box.

---

## Test Plan

Reworking test plan to be aligned with professor's expectations: The tests in your plan are there to prove the manufactured product satisfies your design objectives.

While not falling perfectly under the test plan format, the benchmarking of the Daisy Seed was completed with the added matrix multiplication stress test. In the stress testing, the main takeaway is the the ARM CMSIS library (matrix multiplication implementation specifically) is a great resource to gain measurable code speedups, compared to known algorithm optimization. This is important information for optimizing neural network inference.

---

## Current Testing

With our prior understanding of testing, for special effects, we created 3 graphs to display the multiple gain modulation at multiple different gains upon a simple harmonic note as seen below.

---

## Demo Script

Demo script is currently being developed by all teams collaborating. Proposed flow of demo script:

- intro - overview of pedal purpose/design
- Analog, Software, Embedded talk about signal chain , pre-amp, overdrive, polyphonic detection
- explain protoype's intended action and show if working

---

## Demo Slide

Put together rough draft of demo panel for the presentation. This will give visual explanation of how the pedal works. In the four-section grid we have: top-level view that shows how to use the pedal from guitar to pedal to amp, the aesthetic prototype/physical interface layout including knobs jacks power, software schematic, and high level circuit diagram.

---

## Design Schematic

Design Schematic

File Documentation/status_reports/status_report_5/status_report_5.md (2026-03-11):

# Status Report 5

**Authors:** Yasmeen Amani, Zion, Kai, Barry, Nick, Aaryan
<!-- yall want to insert your last names ? -->

**Date:** February 2026

---

## Collaboration System Links

Github: https://github.com/sbarry753/cse123

---

## Checklist

(-) Not Done (+) Done (=) In Progress ~ Personas

\+ Need Statement

\+ Goal Statement

\= Design Objective

\= Conceptualisations

\= Gantt Chart

\= Aesthetic and Functional Prototypes

\- Design for Manufacture and Assembly

\= Test Plan

\- Test Report

\- Life Cycle Assessment

\- Ethics Statement

\- 3D CAD of final deliverable

\- Design document draft

---

## Weekly Progress Summary

### Benchmarking

The Daisy Seed effect benchmarking was completed this week with the goal determining how complex of an effect is possible and at which block size to keep latency within the acceptable range. In the experiments, we found that the MCU was more than capable of handling effects inspired by the DaisyExamples repository. The greatest Maximum CPU Load measured occurred on a Reverb effect with a block size of 8 at approximately 14\%. This shows how well the MCU can support DSP-related workflows and how optimized the DaisySP library is for audio effects. The full results are documented in this [spreadsheet](https://docs.google.com/spreadsheets/d/1QgfL2nDbECkWdAaCYBFUneOOQhCu9Kp85AZZbPZRD8g/edit?usp=sharing). However, we still want to determine the limits of the Daisy Seed, so we plan on stress-testing it with matrix multiplication. Matrix multiplication is a particularly relevant benchmark because it is computationally demanding and it is used heavily in neural networks, which we are implementing for note/chord detection. We will test different matrix/block sizes and different matrix multiplication algorithms (differing by optimization level).

Furthermore, the memory usage tracking across different effects (mentioned in the last status report) were removed from benchmarking because the choice of effect had no effect on the binary size. The effects and code infrastructure were relatively simple, so the memory usage was trivial. The initial prototype software suite will be much larger.

### Analog effects

Both overdrive circuits were tested with an electric guitar. There was a preference among the group for the sound overdrive circuit based on the Tascam 424 pedal. This week we also began making a schematic and PCB for the overdrive circuit based on a Wampler design. It is uploaded on our Github. We have decided what we are going to present for the initial demo and are working to have the preamp, daisy pod, and overdrive circuit.

### Software: Daisy Pod Effects and Neural Net

---

## Current Personas + Clientele

People who play guitar and want to expand the tonal capabilities of their instrument.

**Current Need Statement**
"Articulate the need as an expression of dissatisfaction with the current situation"

A guitar only makes a guitar sound, and not the sound of other instruments or synthesizers. A musician may have developed intuitive control of the guitar, but cannot easily transfer it to a keyboard or other instrument.

---

## Current Goal Statement

"A brief, general, and ideal response to the need statement"

Design an enviable guitar pedal that detects the notes a guitarist is playing, and plays the same notes through a digital synthesizer.

---

## Decisions Made This Week

- Moving forward with building around daisy seed because Teensy is delayed in shipping
- Chose to make device stand-alone and not a product that has an app or receives updates after purchase
- Plan to order a industry standard metal pedal enclosure from Love My Switches

---

## Test Plan

### Overdrive Clipping

We plan to test that our overdrive circuit is indeed clipping with an oscilloscope and waveform generator. We want to have a soft-clipping effect that pairs well with the effects coming from the synth.

### Overdrive Sound

The overdrive circuit also has to sound good to our ears and the ears of select musicians testing our pedal. We are currently going through this stage of testing with just our guitarist team members and their various guitars and amps. We have multiple op amps and other analog components to test and create an overdrive circuit that excites us and our clientele.

### Embedded System Testing

Currently working on a test plan for the Daisy Seed to make sure it can handle real-time audio processing. Setting tests to check buffer size, polyphonic, sample rate vs latency, and CPU usage. Wrote a program to test full signal chain while monitoring CPU load. Will test by this week when guitar is acquired.

### Demo Prep Test

We plan to meet again this weekend to wire up all sub assemblies of the pedal and test it with a guitar and amp.

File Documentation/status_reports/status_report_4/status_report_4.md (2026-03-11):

# Status Report 4

**Authors:** Yasmeen Amani, Zion, Kai, Barry, Nick, Aaryan <!-- yall want to insert your last names ? -->

**Date:** February 2026

---

## Collaboration System Links

Github: https://github.com/sbarry753/cse123

---

## Checklist

(-) Not Done (+) Done (=) In Progress ~ Personas

\+ Need Statement

\+ Goal Statement

\= Design Objective

\= Conceptualisations

\= Gantt Chart

\= Aesthetic and Functional Prototypes

\- Design for Manufacture and Assembly

\= Test Plan

\- Test Report

\- Life Cycle Assessment

\- Ethics Statement

\- 3D CAD of final deliverable

---

## Timeline

We have been revising and finalizing our timeline to have a working prototype by week 11. Each team have made lists of key requirements to finish by specified weeks. We are prioritizing functionality within our respective teams and collaborating on aesthetic choices together.

---

## Weekly Progress Summary

### Benchmarking

This week, we started benchmarking the Daisy Pod only since the Teensy boards appear to have been lost in transit. As the only difference between the Daisy Seed and Teensy 4.0 is the Teensy has a marginally faster clock speed, we believe the Daisy board will be capable to handle the complexity of our effect.

Now, our main benchmarking attention is spent on testing the Daisy seed with multiple effects, varying in computational demand, with different block sizes and sample rates. For each effect + sample rate + block size, the min, max, and avg CPU load in the callback will be measured. These tests should indicate the maximum complexity of an effect the Daisy seed can support such that the latency is within the acceptable range (8ms) and no audio errors occur. Additionally, for each experiment, the memory usage of the all memory regions (SRAM, flash, etc). will be documented. With this information, we can see if used RAM or Flash memory can bottleneck the complexity of the pedal effect. This weekend, Kai will benchmark the Daisy pod with these strategies in mind.

### Analog effects

Zion has completed a functioning prototype of an analog overdrive effect, based on the Tascam 424 preamp. The effect is intended to be used on the output of the digital synth, or on the guitar signal. Once the synthesizer portion is completed, the EQ section, input gain, and op-amp selection of the analog effect could be tweaked to be more synergistic, and pleasing to listen to.

---

## Current Personas + Clientele

People who play guitar and want to expand the tonal capablilities of their instrument.

**Current Need Statement**
"Articulate the need as an expression of dissatisfaction with the current situation"

A guitar only makes a guitar sound, and not the sound of other instruments or synthesizers. A musician may have developed intuitive control of the guitar, but cannot easily transfer it to a keyboard or other instrument.

---

## Current Goal Statement

"A brief, general, and ideal response to the need statement"

Design an enviable guitar pedal that detects the notes a guitarist is playing, and plays the same notes through a digital synthesizer.

---

## Decisions Made This Week

- Moving forward with building around daisy seed because Teensy is delayed in shipping
- Chose to make device stand-alone and not a smart updatable product

---

## Test Plan

Team Testing
*Figure 1: Team Testing*

We made lists of different tests we would perform to make sure all bases were covered. There are plans to test not only functionality of software, hardware, and analog, but also UX, error handling, and setup instructions. Tests will be ran with special attention to our approach, execution, and documentation.

Chalkboard Test Plans
*Figure 2: Chalkboard Test Plans*

---

## References

[1] Electrosmith, "Daisy Programmer," 2022. [Online] https://flash.daisy.audio/.

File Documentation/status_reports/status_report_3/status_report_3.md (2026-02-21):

Status Report 3
Group 2 CSE 123

#### Checklist 
(-) Not Done (+) Done (~) In Progress
~ Personas
\+ Need Statement
\+ Goal Statement
\- Design Objective
\- Conceptualisations
~ Decision Table
~ Basic Plan 
\- Gantt Chart
\- Aesthetic & Functional Prototypes
\- Design for Manufacture & Assembly
\- Test Plan
\- Test Report
\- Life Cycle Assessment
\- Ethics Statement
\- 3D CAD of final deliverable for prototype showcasing

#### Timeline
As for the prototype demo for finals, we’ve decided to implement a breadboard version with the daisy seed to cause a simple effect (distortion or fuzz) live with an input from a guitar and output through a guitar amp. We will be using a single note to demonstrate the logic of the system and the daisy seed should be able to act as a music pedal, implementing that unique sound effect with hopefully >8ms latency. 

Therefore, to reach this timeline, we want to finish most of the software development by at least week 9, create a hardware and analog interface within the next couple of weeks, and look into artistic developments that could be made along the way. We want to create a functional prototype that both looks nice and works. We’ve divided ourselves into different teams and have updated the github with a Kanban style system.

#### Script
We want to first present our need and goal statements, then show a live demo of our design, with a breadboard and wires to show that rough logic processing as well as supportive CAD and schematic designs to convey what our pedal is capable of doing and implementing a simple workflow to ensure that what we can do is achievable within the given time frame. 

#### Collaboration System Links
Github: [https://github.com/sbarry753/cse123](https://github.com/sbarry753/cse123 )

#### Weekly Progress Summary
This week we….

Meeting 1 (2/9/26)
The embedded systems group met with Zion and talked about benchmarking on teensy and daisy seed. 
Went through details like block size, complexities of audio samples, and processing power.
Created a timeline for gathering metrics and testing latency
As both boards are sufficiently powerful and have small block sizes, latency may not be as big of an issue as previously thought
Still going to benchmark audio latency, but also note ease of development as another metric to choose which microcontroller platform

Meeting 2 (2/10/26)
Discussed with TA our long term plans and utilization of collaborative tools
Took time to understand the holistic picture and what each role needs to accomplish.
Learned about the different effects and pedals capabilities with Nick’s software and equipment.

Meeting 3 (2/12/26)
Went over technical design and overview of the project with Professor Harrison.
Drew how our project final deliverable would look like and also the rough overview of the “smarts” internally. 
Learned some client-sided questioned questions from Professor Harrison such as user accessibility. Since we are most likely to be focussed on musicians who may have no technical experience or people who are buying a pedal for the first time, we have to make it easy to use and may even implement updating capabilities.
Focussed on the final deliverable requirements rather than just focussing on the prototype requirements due at the end of this quarter.

#### Current Personas + Clientele
People who play guitar but want common synth effects like wave folding specifically made for guitars in a guitar pedal form factor

#### Current Need Statement
“Articulate the need as an expression of dissatisfaction with the current situation”

There exists no guitar pedal or it is uncommon that guitar pedals exist that either replicates a specific cool vintage pedal/amp/speaker or does this certain effect using digital and analog components. 

Sometimes, musicians want to create a unique sound that might not be feasible to attain without dedicating lots of time and money to do. Our pedal aims to allow musicians to attain these sounds without having to spend their time and money on a new instrument.

#### Current Goal Statement
“A brief, general, and ideal response to the need statement”

Design an enviable guitar pedal that digitally (or analog + digital) recreates a vintage effect or rare/new/uncommon effect with low enough latency that the effect can be used for live performance and fits within a standard guitar pedal enclosure. We aim to have a >8ms latency to emphasis ease of use.

#### Nick’s Breakthrough with Polyphonic Algorithms
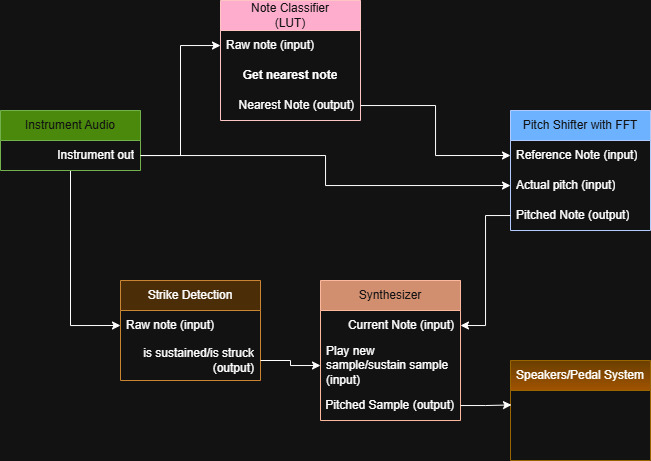
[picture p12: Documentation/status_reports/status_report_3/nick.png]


Nick was able to implement a “polyphonic algorithm” using a table of similar frequencies that can take an input and resemble that frequency to a table with a pitch shifter, that can then output that pitched note for it to be used with the unique effects portion as seen with the schema drawing from before. Right now, it works with a single guitar note, however we hope to extend this to a wider range of guitar pitches and even have it work for different instruments to increase its accessibility. 
Read more about it here:
[https://github.com/sbarry753/cse123/tree/GuitarEffectTrials/LUT%20Development](https://github.com/sbarry753/cse123/tree/GuitarEffectTrials/LUT%20Development)

#### Benchmarking Ideas
Benchmarking Harness
Need a common interface for benchmarking latency across MCUs
This harness should support both MCUs with compiler flags/config changes
Both MCUs would run the same effects
Only difference is board-specific audio I/O
Test different block sizes, sample rates, and effects
The responsibility of the harness is to create MCU-agnostic DSP effects in raw C++
The Daisy/Teensy would call this harness in their audio callback functions
Harness Overview
Contains the effects
Simple, medium, complex effect 
Effects with different block sizes
Entry point function to process audio from callback
In audio callback: store CPU load metrics in buffer (processed outside of interrupt loop)
Number of cycles/time spent in block
CPU utilization
CPU Load Measurement
Daisy
CpuLoadMeter Source
Use CpuLoadMeter class, call OnBlockStart() at beginning of audio callback function and OnBlockEnd() at the end of the function
Can measure CPU load with this class
As the audio effect isn't the only thing the MCU would do (ex. note classification via LUT), would need to make sure there's enough CPU power for audio effect + other MCU responsibilities

#### Current Research Explored
This week we looked at…..

Special effects implementations
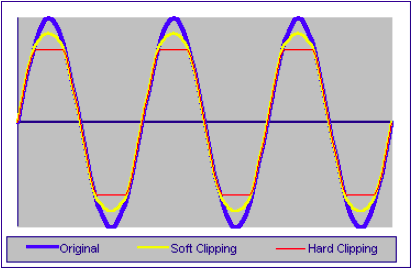
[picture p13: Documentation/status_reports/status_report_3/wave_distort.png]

Distortion effect takes in a waveform and “clips” it so that the natural frequencies produce a more square wavelength that sounds a fuzzy sound.

The overdrive effect is very similar to the distortion effect, in that instead of clipping it from the top, it “squeezes” the waveform from its sides to create a sharper tone. This creates a smoother, creamier tone.

The fuzz effect is an aggressive transformation that changes the signal into a square signal. It creates a sharp, gritty, and aggressive tone.

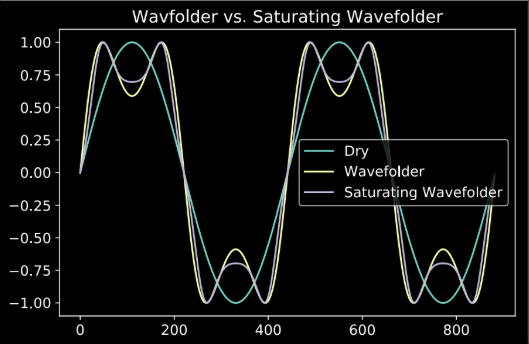
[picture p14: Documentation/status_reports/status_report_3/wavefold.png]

Wavefolding is when the frequency folds into itself after a peak, creating a synthetic sound. This effect is quite difficult and mathematicaly intense, however, it is definetley an achievable effect and a goal for Spring quarter. 

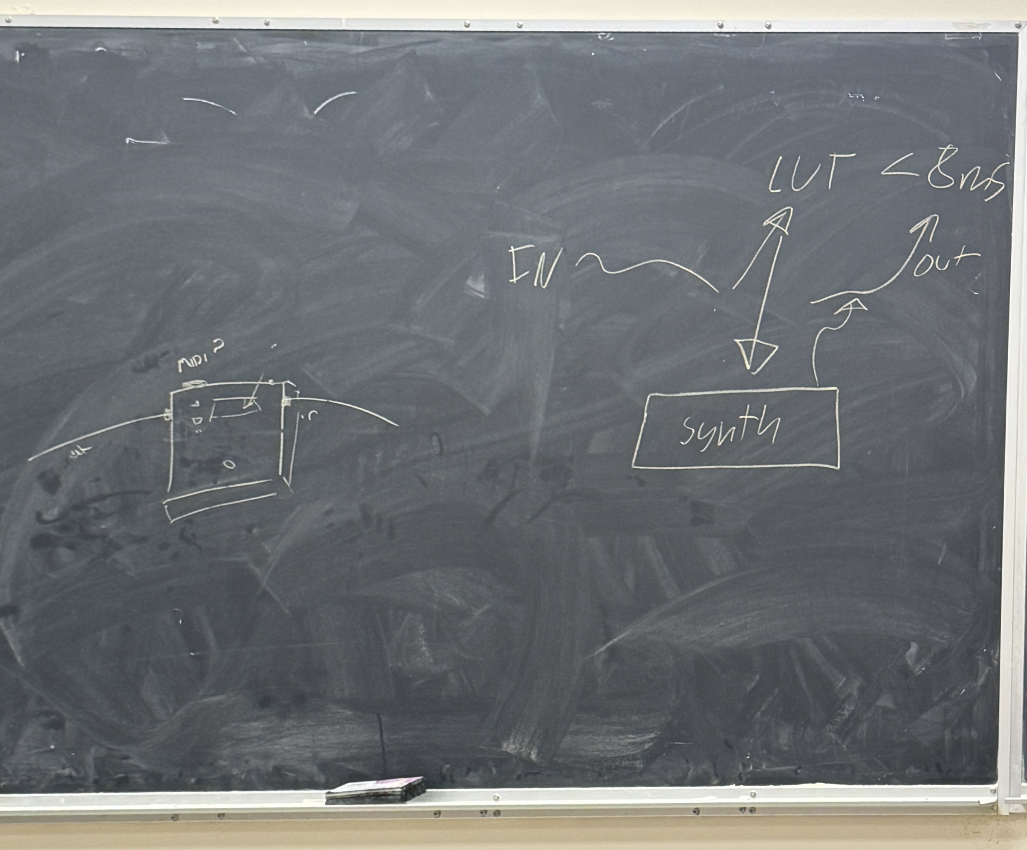
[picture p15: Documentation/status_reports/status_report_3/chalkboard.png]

Figure of chalkboard drawing during professor meeting. On the left is and example mock-up for the physical design of the pedal. On the right is a schematic of the device’s effects process. 

#### Sources
[1] “Beginner guide: Overdrive & distortion pedals,” Andertons Blog, https://blog.andertons.co.uk/learn/distortion-pedal-beginners-guide (accessed Feb. 13, 2026).
[2] J. Chowdhury, “Wavefolding¶,” Wavefolder, https://ccrma.stanford.edu/~jatin/ComplexNonlinearities/Wavefolder.html (accessed Feb. 13, 2026).
[3] “Distortion Explanation,” Distortion Effect Page, https://www.donreiman.com/Distortion/Distortion.htm (accessed Feb. 13, 2026).

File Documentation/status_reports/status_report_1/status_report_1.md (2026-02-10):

**Weekly Progress Summary**
As a group we have been making key design decisions for our project. This week we discussed if we should design a multi-effects guitar pedal vs a single-effect pedal and the pros and cons of each choice. This brought forth other obstacles as we went through the design checklist. We have been constantly reworking our need and goal statements as we question the practicality of our design choices. 

Each completed individual research and brought forth information to the group meetings about hardware, software, parts-ordering, timelines, etc. 

This period consisted of 3 scheduled meetings:

Meeting 1:

* Discussed potential project ideas and proposed many routes of each.  
  * Guitar Pedal/Effects Unit  
  * Book Digitizer  
  * Video Game Console  
  * Bike Helmet Crash Detection  
  * Etc.  
* We ended up narrowing our options down and voting on a project during this meeting.

Meeting 2:

* Met with our TA, and discussed how guitar effects units work  
* Realized there were two solid paths to take and we split into two groups to do research on each of these options and reconvene at the next meeting to discuss the scopes of each

Meeting 3:

* Presented our research  
* Presented viable prototype options  
* Discussed Custom Effects vs an Effects Unit  
* Pushed the decision of which route we will take for our next meeting

We had also established primary means of communication (discord), collaborative tools bringing together contributions. We will be using Google Drive to save important documents, keep a list of important links/materials, and to keep track of status reports and meetings moving forward. We hope to use Github to collaborate directly with the project and any meaningful developmental updates such as code and hardware.

**Next Week’s Goals:**  
We plan to reconvene on Monday 2/1/26 to decide on a multi effects unit or single effect pedal, decide on an embedded or Linux/Windows IoT based pedal, and begin ordering parts for our initial prototype.

*“Articulate the need as an expression of dissatisfaction with the current situation”*

**Current Need Statement**  
Guitar multi effects units don’t allow users to upload effects made with software other than the one the multi effects unit company supplied

OR 

There exists no guitar pedal that either digitally replicates a specific cool vintage pedal/amp/speaker or does this certain effect

*“A brief, general, and ideal response to the need statement”*

***Current Goal Statement***  
Design a multi effects unit that lets users upload their own custom VST effects regardless of the software platform used to create them and is easy to use

OR

Design an enviable guitar pedal that digitally (or analog \+ digital) recreates a vintage effect or rare/new/uncommon effect with low enough latency that the effect can be used for live performance and fits within a standard guitar pedal enclosure  
(define in seconds what low latency for a pedal is)

**Current Research Explored**

*Embedded vs. Linux based pedals*  
We divided the team up to explore our options for which platform would be most doable in the short amount of time we have for our capstone. There was a rising consensus to move forward with an embedded system but we are still exploring our options.

**Current embedded options explored**

Daisy seed: [https://electro-smith.com/products/daisy-seed?variant=45234245140772](https://electro-smith.com/products/daisy-seed?variant=45234245140772)   
Pros: Cheap, fast for prototyping, designed for audio projects  
Cons: Locked in at a lower speed.   
Teensy 4.0: [https://www.pjrc.com/store/teensy40.html](https://www.pjrc.com/store/teensy40.html)   
Pros: Higher processing power, may already have part  
Cons: Audio Implementation isn’t intuitive, may require audio shield

RPi 20240: [https://www.raspberrypi.com/products/rp2040/](https://www.raspberrypi.com/products/rp2040/)  
Pros: Cheap  
Cons: Low speed operations (higher latency)

**Current Linux options explored**

Pi-Stomp: [https://www.treefallsound.com/wiki/doku.php?id=start](https://www.treefallsound.com/wiki/doku.php?id=start)   
Pros: proof that hobbyist multi effect pedals that are Linux based exist, RPi5 is powerful and can achieve the low latency we’re looking for  
Cons: this completed project showed how difficult it may be to complete in our short amount of time, the project we had in mind is this team’s 3rd iteration, expensive

Pedal Pi: [https://www.electrosmash.com/pedal-pi](https://www.electrosmash.com/pedal-pi)   
Pros: RPi zeros are pretty cheap, a completed project to improve upon  
Cons: only one effect, unable to find the schematic and pcb files, dead project

**Current Windows options explored**  
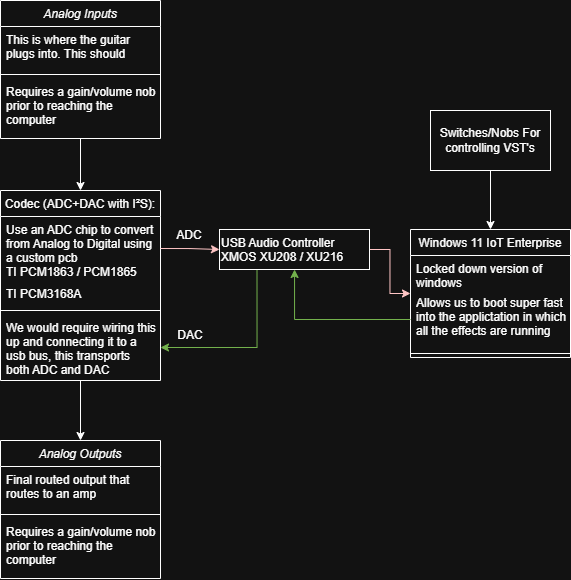
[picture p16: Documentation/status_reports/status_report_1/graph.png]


Pros: User friendly, easily use VSTs, very powerful.  
Cons: Not much embedded programming going on, custom effects wouldn’t be a part of this project's scope.

**Guitar pedal standards, parts sourcing and manufacturing**

[Love My Switches](https://lovemyswitches.com/%20) is a hobbyist DIY and pedal repair site that offers a lot of parts for building and repairing pedals and has quick shipping. We can use them to source metal enclosures, switches, knobs, potentiometers, power switches and jacks, LEDs, audio jacks, and drill jigs.

[Mouser](https://www.mouser.com/) is an online supplier of electrical components

[Digikey](https://www.digikey.com/) is an online supplier of electrical components

[McMasterCarr](https://www.mcmaster.com/) is an online supplier of PPE, tools, raw materials, office supplies and anything else you need to make a factory this week

[PCBWay](https://www.pcbway.com/) can make and assemble PCBs and fabricate any 3D models we send over with CNC machining or 3D printing. PCBWay can possibly be a sponsor since they have previously sponsored one of our group members. WARNING NO MANUFACTURING DURING LUNAR NEW YEAR: FEB 15th \- FEB 18th

[JLCPCB](https://jlcpcb.com/) can make and assemble PCBs. WARNING NO MANUFACTURING DURING LUNAR NEW YEAR: FEB 16th \- FEB 19th

[Slugworks](https://slugworks.engineering.ucsc.edu/) makerspace is on campus and has a lot of tools that undergraduates have access to after going through the trainings.

[Pawprint Prototyping](https://pawprintprototyping.org/) is a makerspace open to the public in Santa Clara with different tools than Slugworks offers. One of our group members holds a membership with the ability to supervise members of the public using the makerspace’s tools.

**Guitar Effects Creation**

If we go the embedded route, we need a way to make audio effects. There are numerous tools to assist in creating these effects. The Daisy ecosystem already has an open-source library (C++)  for DSP: [https://github.com/electro-smith/DaisySP](https://github.com/electro-smith/DaisySP). Another approach for DSP would be to use a tool that compiles into C++ to use on an embedded device such as MATLAB and [FAUST](https://faustdoc.grame.fr/). FAUST is a functional language with an online IDE, which can be used to create effects and listen to audio output right on your computer. This may allow us to speed up effects development, but more research is needed. 

**Hardware Motherboard**

We were looking into the [Daisy Pod](https://electro-smith.com/products/pod) which has lots of the connecting hardware we require for the project, however it only has two knobs and buttons which is vastly different from our objective goals. Technically, we could string together many of these pods, but that is an expensive, unoptimized solution. Therefore, we may buy a Daisy Pod for testing software purposes, but for our final goal, we will be making a custom PCB that supports many different types of inputs and allows for multiple pedal support for our final deliverable.   
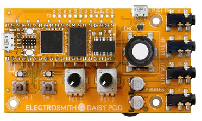
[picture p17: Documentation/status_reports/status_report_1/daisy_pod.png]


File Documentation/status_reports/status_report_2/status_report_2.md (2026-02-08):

#### Collaboration System Links
Github: [https://github.com/sbarry753/cse123](https://github.com/sbarry753/cse123) 

#### Weekly Progress Summary
This week we….

Meeting 1 (2/2/26)
- Discussed muti-effect vs single-effect pedal
- Formulated roles and went over skill sets
- Roles decided: Analog, Embedded Systems, Artistic Director

Meeting 2 (2/3/26)
- Went over status report submission guidelines with the Karan. He suggested recording: How much time was spent working and which person did which aspect? 
- TA proposed questions to consider; What has been done? What is in progress? What work needs to be completed in the future?

Meeting 3 (2/4/26)
- Barry and Nick met to deliver the first Daisy Pod to begin designing the initial prototype of the digital effect 

Meeting 4 (2/5/26)
- Spent time with Prof Harrison to talk about team management strategies
- The sign of a healthy team is one that assigns tasks to themselves
- Keep the kanban board simple with 4 categories maximum (backlog, todo, in progress, done)
- Showed off Nick’s demo of the digital effect so far
- Confirmed that Prof Harrison is a musician and specifically plays guitar, bass and piano
- He doesn’t use effects but he likes the sound of amps from British brands like Vox

#### Checklist 
(-) Not Done (+) Done (~) In Progress

~ Personas

\+ Need Statement

\+ Goal Statement

\- Design Objective

\- Conceptualisations

~ Decision Table

~ Basic Plan - Gantt Chart

\- Aesthetic & Functional Prototypes

\- Design for Manufacture & Assembly

\- Test Plan

\- Test Report

\- Life Cycle Assessment

\- Ethics Statement

#### Current Personas
People who play guitar but want common synth effects like wave folding specifically made for guitars in a guitar pedal form factor
#### Current Need Statement
There exists no guitar pedal or it is uncommon that guitar pedals exist that either replicates a specific cool vintage pedal/amp/speaker or does this certain effect using digital and analog components
#### Current Goal Statement
Design an enviable guitar pedal that digitally (or analog + digital) recreates a vintage effect or rare/new/uncommon effect with low enough latency that the effect can be used for live performance and fits within a standard guitar pedal enclosure
#### Decisions Made This Week
- Purchased Daisy Seed + Daisy Pod and Teensy 4.0 + Teensy Audio Shield to test out these platforms for digital effects creation
- Began to outline roles and assign them amongst the team members most interested
- Started a github repo and github project

#### Design Plan Decision Defense
We chose the Daisy Seed and Teensy 4.0 platforms because they match our need for processing guitar effects. The Daisy Seed’s purpose is to be used in audio hardware devices and is open-source so that was a clear option for us to try. Teensy 4.0 has an audio library and audio board. This is a fast microcontroller with low latency and real time digital signal processing. From here we will evaluate each microcontroller and compare which choice is superior for our project's needs. Specifically focusing on comparing latencies.

#### Morphological Chart Rough Draft
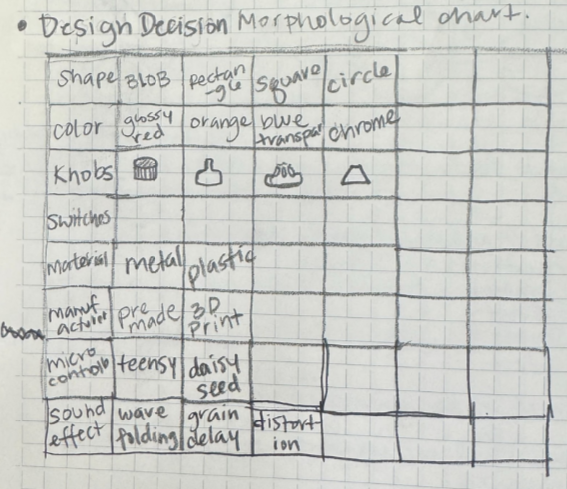
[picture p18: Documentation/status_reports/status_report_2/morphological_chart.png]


#### Current Research Explored
This week we looked at…..

**Different Effects**
- Wave folding
- distortion
- fuzz
- overdrive

Through our research with Daisy Seed, in performing a wavefolding sound effect for the pedal, there's a few concerns we have to consider. The general flow of our design would be something like this:

Guitar Sound --> Input Buffer --> Preamp Gain --> ADC --> DAC --> Reconstruction Filter --> Output Buffer --> Amp (as seen in Status Report #1)

The Daisy Seed microcontroller provides built-in ADC-DAC control, however everything else would be connected to the PCB and may require analog controls to interact with the Daisy Pod. We may have to add or remove some things during the prototyping process as well.

Some concerns with the wavefolding effect we are aiming for is that transmitting the guitar signal, since it's a high-impedance source, needs to cleanly be transmitted and attunated through the Daisy Seed.  

**Trying to find acceptable latency (extremely important design constraint)**
-  How to score latency (likely a nonlinear response curve of latency -> “perceived quality”)
- Designing an experiment to measure latency (in progress)
- Requires a Y-splitter cable or stereo out device, audio interface with 2+ inputs, digital audio workstation… all of which are on hand
- Jitter (variation in latency) is an additional concern
- Lower is better, 10ms (w/~1ms jitter) is described as a target for digital musical instruments
- Sources
	- R. H. Jack, A. Mehrabi, T. Stockman, and A. McPherson, “Action-sound Latency and the Perceived Quality of Digital Musical Instruments,” Music Perception, vol. 36, no. 1, pp. 109–128, Sep. 2018, doi: [10.1525/mp.2018.36.1.109](https://doi.org/10.1525/mp.2018.36.1.109).
	- A. Schmid, M. Ambros, J. Bogon, and R. Wimmer, “Measuring the Just Noticeable Difference for Audio Latency,” in Audio Mostly 2024 - Explorations in Sonic Cultures, Milan Italy: ACM, Sep. 2024, pp. 325–331. doi: [10.1145/3678299.3678331](https://doi.org/10.1145/3678299.3678331).

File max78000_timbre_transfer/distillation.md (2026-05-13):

# Model Distillation

This file outlines the process of distilling the model from `TIMBRE NET - In Developent`, partially using the framework provided by **Analog Devices** from training and synthesis *(see [ai8x-training](https://github.com/analogdevicesinc/ai8x-training) and [ai8x-synthesis](https://github.com/analogdevicesinc/ai8x-synthesis))*

## Distilled Model Architecture
The small student model is defined in `TIMBRE NET - In Developent/model_distilled.py`. Currently, it is a simple 5-layer CNN. Each layer has a 3x3 kernel with a stride and padding of 1. 

## TODO Steps
1. Train model with ai8x-training train.py
2. Quantize with ai8x-synthesis quantize.py
3. Generate code with ai8x-syntheses ai8xize.py

python train.py --device MAX78000 --model timbrestudent --dataset MAXGuitarPiano --data ../../TIMBRE\ NET\ -\ In\ Developent/data --regression --use-bias -j 0

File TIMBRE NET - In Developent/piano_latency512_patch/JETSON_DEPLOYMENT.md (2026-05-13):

# Jetson Orin pruning/export/deployment

## 1. Export on your training machine

Use the trained 512-window checkpoint from this patched project. Do **not** use an older 1024-window checkpoint unless the architecture constants match.

```bash
python prune_export_jetson.py \
  --checkpoint ./checkpoints/best_model.pt \
  --output_dir ./jetson_export \
  --prune_amount 0.35 \
  --device cuda
```

This creates:

- `jetson_export/model_pruned_scripted.pt`
- `jetson_export/model_pruned_checkpoint.pt`
- `jetson_export/jetson_realtime.py`
- `jetson_export/model.py`
- `jetson_export/jetson_deploy_bundle.tar.gz`

## 2. Copy to Jetson

```bash
scp jetson_export/jetson_deploy_bundle.tar.gz jetson@JETSON_IP:~/
ssh jetson@JETSON_IP
mkdir -p ~/piano_jetson
mv ~/jetson_deploy_bundle.tar.gz ~/piano_jetson/
cd ~/piano_jetson
tar -xzf jetson_deploy_bundle.tar.gz
```

## 3. Run playback like the old `--play` mode

```bash
python3 jetson_realtime.py \
  --model ./model_pruned_scripted.pt \
  --input ./guitar.wav \
  --play
```

Save while playing:

```bash
python3 jetson_realtime.py \
  --model ./model_pruned_scripted.pt \
  --input ./guitar.wav \
  --play \
  --output ./piano_out.wav
```

Live input:

```bash
python3 jetson_realtime.py --model ./model_pruned_scripted.pt --live
```

List devices:

```bash
python3 jetson_realtime.py --list-devices
```

Then pass device indexes if needed:

```bash
python3 jetson_realtime.py \
  --model ./model_pruned_scripted.pt \
  --input ./guitar.wav \
  --play \
  --output_device 0
```

## Notes

- Unstructured pruning helps compression and can regularize the model, but dense PyTorch CUDA kernels may not get much faster from zeros alone.
- For real Jetson speed, the biggest wins are: the 512-frame model, TorchScript, CUDA, `torch.inference_mode()`, and the normalized overlap-add engine.
- If pruning hurts piano quality, try `--prune_amount 0.15` or `0.25`.
- If quality survives, try `0.45`. I would not start above `0.50` for audio.
- Keep output `--volume` around `0.8` to `0.9` while testing distortion.

Optional Jetson performance mode:

```bash
sudo nvpmodel -m 0
sudo jetson_clocks
```

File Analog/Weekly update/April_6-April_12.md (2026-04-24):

# Analog — April 6 to April 12

## Hardware
- Jetson Orin arrived and was distributed to the team

## Components
- Compressor and distortion circuit parts arrived

## Workflow Update
- Stopped transporting analog parts between house, dorm, and lab
- Committed to working exclusively in the lab

## Orders Finalized
- Reverb circuit

## Circuit Development

### Modified Electra Distortion Circuit
- Built and tested a modified Electra distortion circuit
- Experimented with multiple transistors to compare sound characteristics
  - Preferred option: **2N3904**
- Feedback:
  - Guitarist teammates responded positively to the sound

### Planned Improvements
- Add toggle to turn the distortion effect on/off
- Create schematic for the modified circuit

### Priority
- Low priority (not essential for improving synthesized instrument sound)

### Reference
- https://crazychickenguitarpedals.com/guitar-pedal-blog/guitar-pedal-builds/building-a-simple-distortion-pedal-based-on-the-electra-distortion/

Electra circuit

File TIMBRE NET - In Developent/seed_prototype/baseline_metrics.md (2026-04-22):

# Experiment 1: Boost=true

**Metadata**
- CPU Hz: 480000000
- Frame/Hop: 512 / 128
- STFT bins/frames: 257 / 5
- Feature channels: 9
- Model params: 859053
- Weight bytes: 3436212
- Scratch bytes: 1472676
- Static total bytes: 4908888
- Warmup/bench: 5 / 20
- Compiler Optimizations: -O2
- Weights Location: QSPI

**Metrics**
|Case|min cyc|avg cyc|max cyc|min us|avg us|max us|avg hop budget|max abs err|rmse|
|---|---|---|---|---|---|---|---|---|---|
|Zero| 134344255 | 135168699 | 135575007 | 279883.864 | 281601.456 | 282447.931 | 10560.05% | 0.0 | 0.0 |
|Impulse| 133524175 | 134290033 | 134982663 | 278175.364 | 279770.902 | 281213.881 | 10560.05% | 0.0 | 0.0 |
|Random| 136208827 | 137029543 | 138208495 | 283768.389 | 285478.214 | 287934.364 | 10705.43% | 0.0 | 0.0 |

# Experiment 2: -O3 -ffast-math
**Metadata**
- CPU Hz: 480000000
- Frame/Hop: 512 / 128
- STFT bins/frames: 257 / 5
- Feature chans: 9
- Model params: 859053
- Weight bytes: 3436212
- Scratch bytes: 1472676
- Static total bytes: 4908888
- Compiler Optimizations: -O3 -ffast-math
- Weights Location: QSPI

|Case|min cyc|avg cyc|max cyc|min us|avg us|max us|avg hop budget|max abs err|rmse|
|---|---|---|---|---|---|---|---|---|---|
|Zero| 105296319 | 105869290 | 106648751 | 219367.331 | 220561.020 | 222184.897 | 8271.03% | 0.0 | 0.0 |
|Impulse| 103999127 | 104848747 | 105502279 | 216664.847 | 218434.889 | 219796.414 | 8191.30% | 0.0 | 0.0 |
|Random| 107231577 | 107787570  | 108203207 | 223399.118 | 224557.437 | 225423.347 | 8420.90% | 0.0 | 0.0 |

# Experiment 3: -O3 -ffast-math SDRAM
**Metadata**
- CPU Hz: 480000000
- Frame/Hop: 512 / 128
- STFT bins/frames: 257 / 5
- Feature channels: 9
- Model params: 859053
- Weight bytes: 3436212
- Scratch bytes: 4910936
- Static total bytes: 8347148
- Compiler Optimizations: -O3 -ffast-math
- Weights Location: SDRAM

|Case|min cyc|avg cyc|max cyc|min us|avg us|max us|avg hop budget|max abs err|rmse|
|---|---|---|---|---|---|---|---|---|---|
|Zero| 161249769 | 162130716 | 162673937 | 335937.018 | 337772.325 | 338904.035 | 12666.46% | 0.0 | 0.0 |
|Impulse| 160754913 | 161140860 | 161877181 | 334906.068 | 335710.125 | 337244.127 | 12589.12% | 0.0 | 0.0 |
|Random| 163274432 | 163776221 | 164525021 |340155.066 | 341200.460 | 342760.460 | 12795.01% | 0.0 | 0.0 |

# Experiment 4: -O3 -ffast-math int8 Quantization TFLM
**Metadata**
- CPU Hz: 480000000
- Frame/Hop: 512 / 128
- STFT bins/frames: 257 / 5
- Feature channels: 9
- Activation note: quick-gelu approx in exported TFLite mirror
- UNet model bytes: 932584
- Transient model bytes: 29912
- DSP scratch bytes: 157132
- Reserved arena bytes: 3407872
- Static reserved total: 4527500
- UNet arena used/reserved: 193628 / 3145728
- Transient arena used/reserved: 54916 / 262144
- Compiler Optimizations: -O3 -ffast-math
- Weights Location: QSPI
- int8 quantization

|Case|min cyc|avg cyc|max cyc|min us|avg us|max us|avg hop budget|max abs err|rmse|
|---|---|---|---|---|---|---|---|---|---|
|Zero| 1327903565 | 1328184965 | 1328621069 | 2766465.760 | 2767052.010 | 767960.560 | 103764.45% | 1.336782 | 0.913601 |
|Impulse| 1327792401 | 1328205556 | 1328664525 | 2766234.168 | 2767094.908 | 2768051.093 | 103766.05% | 0.215599 | 0.029597
|Random| 1327907661 | 1328198052 | 1328492277 | 2766474.293 | 2767079.275 | 2767692.243| 103765.47% | 0.119147 | 0.035504

**Case: zero**

avg stage us: pre=9427.447 unet=2671944.408 recon=3663.522 transient=81983.093

**Case: impulse**

avg stage us: pre=9388.445 unet=2672816.268 recon=3724.139 transient=81132.537

**Case: random**

avg stage us: pre=9444.110 unet=2672239.333 recon=3741.095 transient=81620.352

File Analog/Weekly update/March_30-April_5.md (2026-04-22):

# Analog — March 30 to April 5

## Hardware
- Ordered Jeston Orin for hardware prototyping

## Orders Finalized
- Electra distortion
- Compression circuits

## Research

### Compression Circuits
- Researched compression circuits  
  https://www.youtube.com/watch?v=Wag-yTyAxPA

### Reverb Pedals

- Researched reverb pedals and required chips
- Decision: **Digital reverb** (not spring reverb)

### Chip Options
- PT2399
- BTDR-1H (“Belton Brick”)

### Component Considerations
- Ensure correct chip selection:  
  https://e2e.ti.com/support/amplifiers-group/amplifiers/f/amplifiers-forum/869344/tl072-10db-increase-in-noise-when-using-tl072cp-vs-tl072ip

## Build Plans

- Likely build:  
  https://www.diyguitarpedals.com.au/shop/boms/Boy%20in%20Well.pdf  
  https://www.youtube.com/watch?v=N7Y_1qoq_eM

## Additional Resources

- Hard-to-follow reverb guide:  
  https://www.youtube.com/watch?v=aolHQmIhiY8&t=21s  
  https://tagboardeffects.blogspot.com/2012/03/ersatz-verben-psuedo-reverb-by.html

- Belton Brick reverb demo:  
  https://www.youtube.com/watch?v=L5s1v7O9rn4&t=406s

- Cheap spring reverb option (not practical for this project):  
  https://www.youtube.com/watch?v=JBb6G1VJM-I

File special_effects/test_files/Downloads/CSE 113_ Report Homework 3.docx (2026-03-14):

# CSE 113 Homework 1

# Report

## 1. Producer-consumer Queues

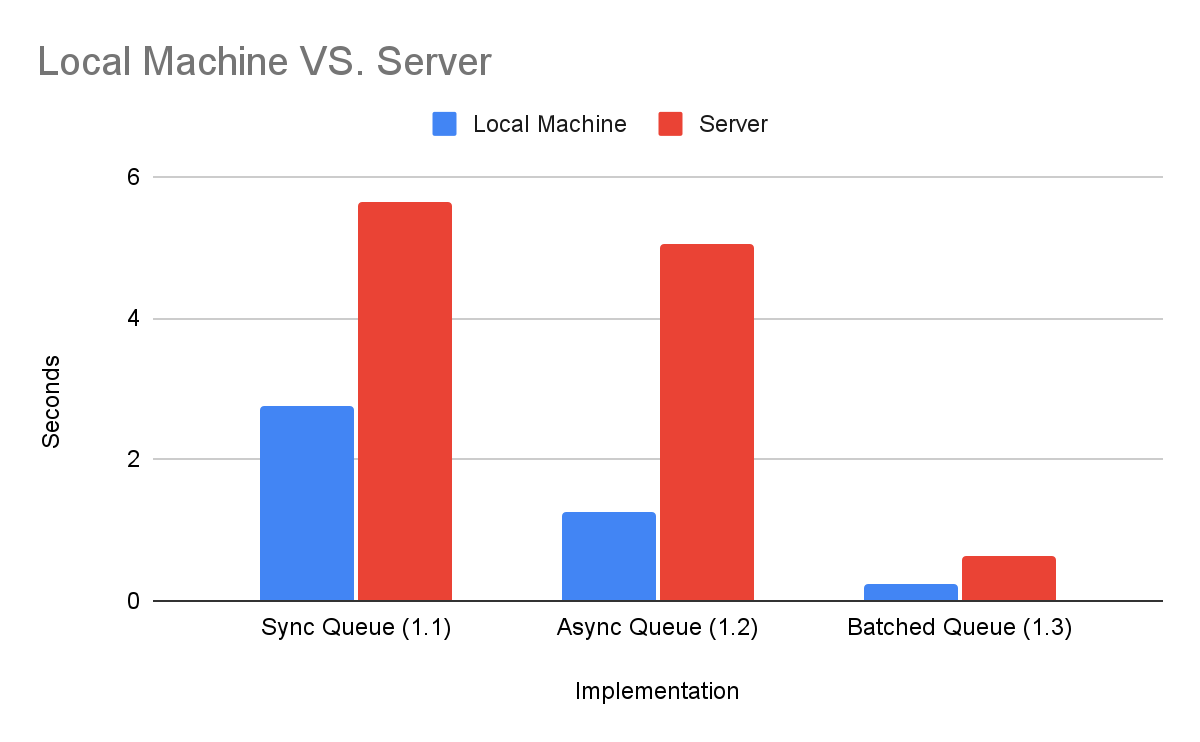
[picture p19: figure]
Local Machine VS. Server

Implementation | Local Machine | Server
Sync Queue (1.1) | 2.75016 | 5.62675
Async Queue (1.2) | 1.24513 | 5.04348
Batched Queue (1.3) | 0.234106 | 0.648953

For the synchronous queue, I implemented a handoff mechanism using two atomic booleans where the producer spins until the consumer is ready and vice versa, enforcing a strict one-at-a-time exchange as discussed in lecture. For the asynchronous queue, I used a circular buffer of size 2048 with two monotonically increasing atomic integers for head and tail, where size is simply tail minus head which avoids any wraparound edge cases. For the batched version, I extended the async queue with enq_8 and deq_8 functions that check for 8 available slots or items before proceeding and advance the head or tail by 8 atomically after completing the batch. One challenge I ran into was a data race flagged by ThreadSanitizer between the load and store threads sharing the same array, which I resolved using __atomic_load_n and __atomic_store_n with SEQ_CST ordering since the atomic builtins don't natively support floats, requiring a memcpy to reinterpret the bits safely.

Something really interesting from the results is just how dramatic the improvement from batching was on the server, the batched queue ran at 0.65 seconds compared to 5.04 seconds for async and 5.63 seconds for sync, which is roughly an 8-9x speedup over async alone. I didn't expect the gap to be that large. On my local machine the pattern held the same with sync at 2.75 seconds, async at 1.25 seconds, and batched at just 0.23 seconds. The async queue being faster than sync makes intuitive sense since the async queue allows the producer to keep filling the buffer without waiting for each individual dequeue, reducing idle spinning time. The batch improvement is even more significant because it reduces the number of total enqueue and dequeue operations by a factor of 8, which means far fewer atomic operations and less synchronization overhead overall. The server showed a bigger relative gap between sync and async than local, which could be due to the server having more cores and thus more contention on individual atomic operations in the synchronous case.

## 2. DOALL Loop Parallel Schedules

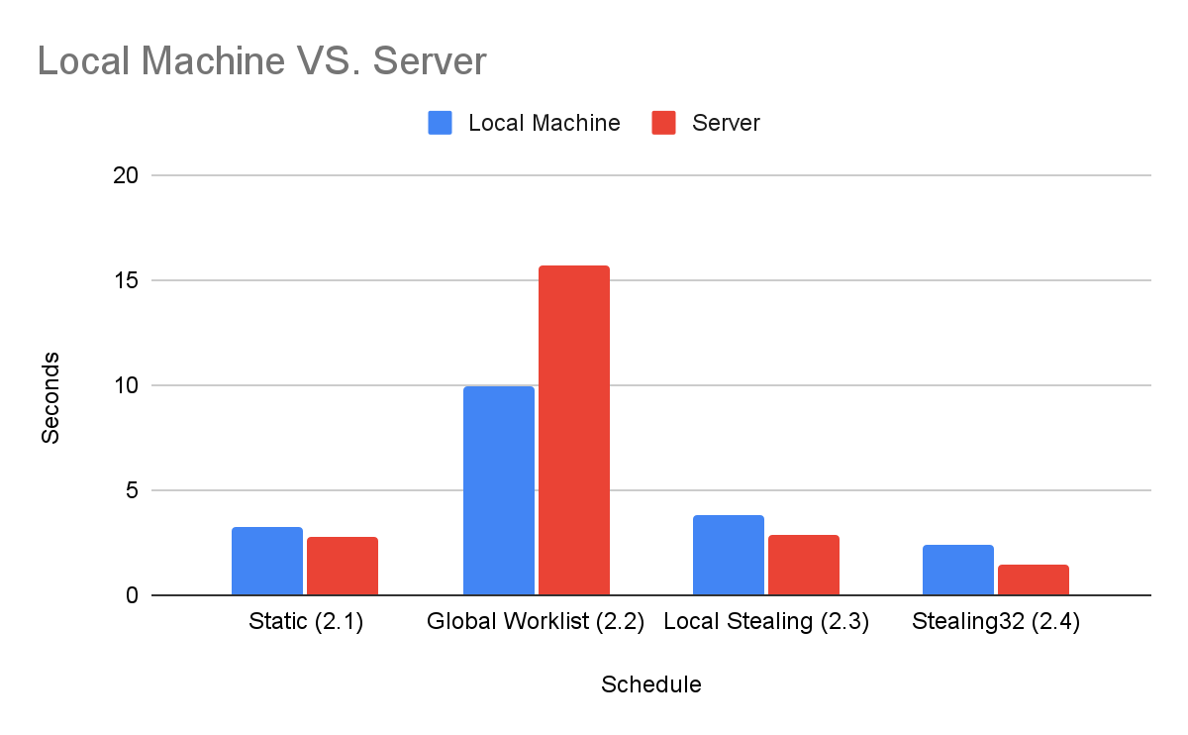
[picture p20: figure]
Local Machine VS. Server

Implementation | Local Machine | Server
Static (2.1) | 3.228 | 2.74078
Global Worklist (2.2) | 9.98169 | 15.6648
Local Stealing (2.3) | 3.77172 | 2.84558
Stealing32 (2.4) | 2.37955 | 1.49057

For the static schedule, I split the index space into contiguous chunks where thread 0 gets indices 0 through size/num_threads and each subsequent thread gets the next chunk, which is straightforward but creates load imbalance since linear_work assigns more work to higher indices. For the global worklist, I replaced the static partition with a shared atomic counter where each thread does a fetch_add to claim the next index, naturally load balancing but creating contention on that single counter. For the local worklist, I implemented an IOQueue with atomic head and tail pointers that supports either parallel enqueues or parallel dequeues but not both simultaneously, then initialized each thread's queue with a chunked range before launching the computation phase where threads drain their own queue first and steal from others when empty. For stealing32, I extended deq_32 to atomically claim 32 indices at once with a single fetch_add and roll back if 32 weren't available, then updated the computation threads to process batches of 32 at a time.

The most surprising result by far was how slow the global worklist was 9.98 seconds locally and 15.66 seconds on the server, which is actually slower than single threaded static in some cases. I didn't expect the atomic counter contention to be that severe, but with 8 threads all hammering the same atomic variable for every single index it makes sense that the overhead dominates. The static schedule performed reasonably well at 3.23 seconds locally and 2.74 seconds on the server despite the load imbalance, which suggests that for this particular workload the imbalance isn't catastrophic enough to kill performance entirely. The local stealing was a big improvement over global at 3.77 seconds locally and 2.85 seconds on the server since each thread mostly works from its own queue and only uses atomic operations when stealing. The stealing32 results were the best overall at 2.38 seconds locally and 1.49 seconds on the server, which mirrors the batching improvement we saw in part 1, fewer atomic operations for the same amount of work means less synchronization overhead and better throughput. The server consistently outperformed local for stealing and stealing32, likely because it has more physical cores that can truly run in parallel without sharing resources.

# Design Document

## 1. Producer-consumer Queues

For the synchronous queue, my thought process was to keep it as simple as possible and stick to what was discussed in lecture. I used two atomic booleans, one to signal that an item is ready to be consumed and one to prevent the producer from overwriting before the consumer picks it up. The producer spins until the consumer clears the flag, and vice versa, enforcing the one-at-a-time handoff. The hardest part was getting the ordering of the flag updates right so that neither thread could race past the other. For the asynchronous queue, I used a circular buffer with two atomic integers for the head and tail. Rather than storing modulo indices directly, I kept them as monotonically increasing integers and only applied the modulo when indexing into the buffer, which made the size calculation trivially correct as just tail minus head. The trickiest part here was the size check for enq_8 and deq_8, since I needed to check for 8 slots of space or 8 items available rather than just 1, which required a slightly different condition than the single element case.

For the synchronous queue in CQueueSync.h, my thought process was to keep it simple and stick closely to what was discussed in lecture. I used two atomic booleans has_item and waiting_for_deq to coordinate the handoff between producer and consumer. The producer first spins until the previous item has been consumed, then writes the item and sets both flags. The consumer spins until has_item is true, reads the value, and clears the flag. The ordering of these flag updates was the trickiest part since getting them wrong would cause either a deadlock or a race where the producer overwrites before the consumer reads. The key insight was that the producer needs to wait on two conditions: first that the consumer is ready, and second that the consumer has actually picked up the item after it was placed.

For the asynchronous queue in CQueue.h, I used a circular buffer of size CQUEUE_SIZE with two atomic integers for head and tail. Rather than storing the indices already reduced by modulo, I kept them as monotonically increasing integers and only applied the modulo when indexing into the buffer. This made the size calculation trivially correct as just tail - head, which avoids any wraparound edge cases. The producer spins while the buffer is full (size == CQUEUE_SIZE) and the consumer spins while it is empty (size == 0). For enq_8 and deq_8, the size check is slightly more involved. I had to check for 8 available slots or 8 available items rather than just 1 before proceeding, and then atomically advance the head or tail by 8 after writing or reading the batch. This ensures that neither the producer nor consumer ever partially completes a batch operation.

For part3_thread_funcs.h, I adapted the single-element thread functions from main.cpp to operate in batches of 8. Each function uses a local batch array, loads or stores 8 elements at a time, and calls enq_8 or deq_8 accordingly. One challenge that came up during testing was a data race flagged by ThreadSanitizer between the memory load thread reading from array a and the memory store thread writing back to the same array. Even though the pipeline ordering through the queues logically prevents them from ever touching the same index simultaneously, TSan cannot prove this. I resolved this by using __atomic_load_n and __atomic_store_n with __ATOMIC_SEQ_CST memory ordering, using memcpy to safely reinterpret the float bits as integers since the atomic builtins only natively support integer types. This made the synchronization relationship explicit enough for TSan to accept.
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

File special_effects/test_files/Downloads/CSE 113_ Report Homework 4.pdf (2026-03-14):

# Report

### 1. Single threaded Web Worker

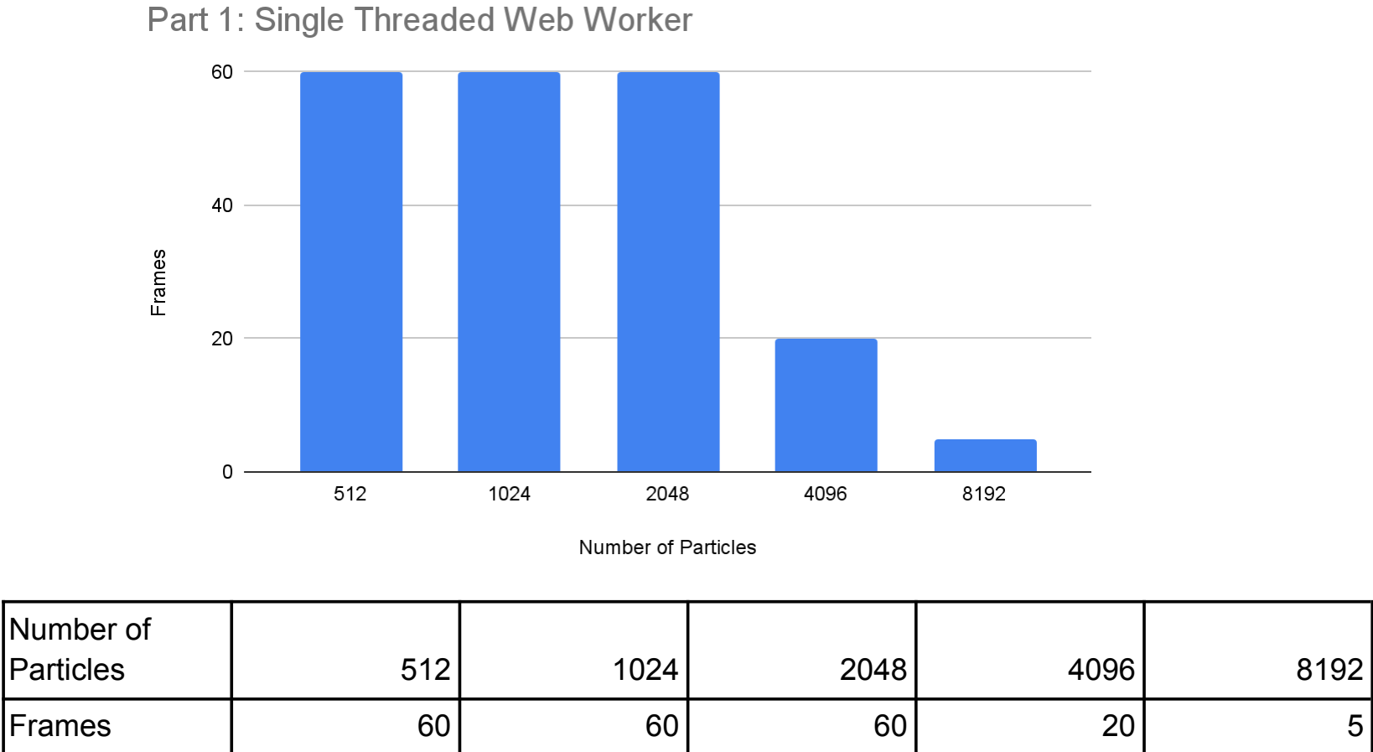
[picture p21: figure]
Number of Particles; Frames

The single threaded web worker implementation achieved 60 FPS at up to 2048 particles, with performance dropping to 20 FPS at 4096 and 5 FPS at 8192. This matches exactly what I expected from the O(N²) complexity of the nested for loop, since doubling the number of particles quadruples the number of distance computations required per frame. The sharp drop between 2048 and 4096 is consistent with this trend, as the single thread becomes the bottleneck once the computation per frame exceeds what can be completed within the 16ms budget for 60 FPS. The results confirm that a single web worker is fundamentally limited by the serial nature of JavaScript execution and cannot take advantage of the multiple cores available on modern hardware.
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

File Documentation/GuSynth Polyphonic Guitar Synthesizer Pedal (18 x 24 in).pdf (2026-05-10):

Group 2 Logo ?

# Design Objectives

Polyphonic Note Detection - Accurately infer the number of distinct notes played in a chord and their individual pitches.

Low Latency (<10 ms) - The player must not perceive any delay between playing and hearing the synthesized sound.

Pedal Form Factor - Fits a standard pedalboard, accepts 9V DC center-negative power, and matches the design language of existing guitar effects pedals.

# Hardware Desgin

# GUSYNTH

# POLYPHONIC GUITAR SYNTHESIZER PEDAL

### Authors

Aaryan, Barry, Kai, Nick, Yasmeen, Zion
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

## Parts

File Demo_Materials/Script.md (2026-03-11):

# Polyphonic Synth Pedal Demo Script
Group 2
March 2026

## Setup for Demo
- Connect guitar to pedal input (right side jack)
- Connect pedal output (left side jack) to guitar amplifier
- Power on pedal
- Display demo slide with 4 panels

## Script

### Intro
**[NAME]:** Hello everyone, welcome to our senior design project demonstration. We chose to design a polyphonic synth guitar pedal. Today we will be showcasing our initial prototype.

**[NAME]:** Quick rundown for those who are not familiar with guitars. Normally when you plug a guitar into an amp, you get an as expected guitar sounds. What if you want your guitar to produce a different sound/different instrument? That is exactly what our guitar pedal does. You play the guitar like normal and it figures out what notes you're playing and....

### Need/Goal Statement & Design Requirements
**[NAME]:** This is our need statement. That is the problem simplified... which in turn led us to this goal statement. Which is the best solution possible after rigorous testing, here is how we met that goal with this prototype and these requirements.

### System Overview - Demo Panel Walkthrough?
**[NAME]:** Here is our demo panel. This top-left section shows the overall signal flow—guitar goes in, gets processed by our pedal, comes out to your amp.

**[NAME]:** Top right is the aesthetic prototype/physical interface. Power switch is right here, input jack on the right, output on the left. These knobs will control... 

**[NAME]:** Bottom left section is this..

**[NAME]:** Bottom right section is this..

**[NAME]:** These components that are grayed out are not implemented in this initial prototype yet. They have been replaced by temporary alternatives . Explain what alternative is doing and why it is there. 

**[NAME]:** Now that you can see how everything connects, lets  hear it work.

### Live Demonstration
**[NAME]:** Here we will show you what we have working. 

**[NAME]:** After hooking up all the cables to the correct jacks, calibrate the pedal with...

**[NAME]:** Then we can choose effect with this knob. Here this button performs this task. Now we can alter the original sound from the instrument to sound like this. 

Play guitar. Should produce intended sound/clear signal. 

**[NAME]:** Now you can hear the guitar.

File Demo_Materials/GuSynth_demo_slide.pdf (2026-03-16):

## GuSynth - A Polyphonic Guitar Synthesizer Pedal

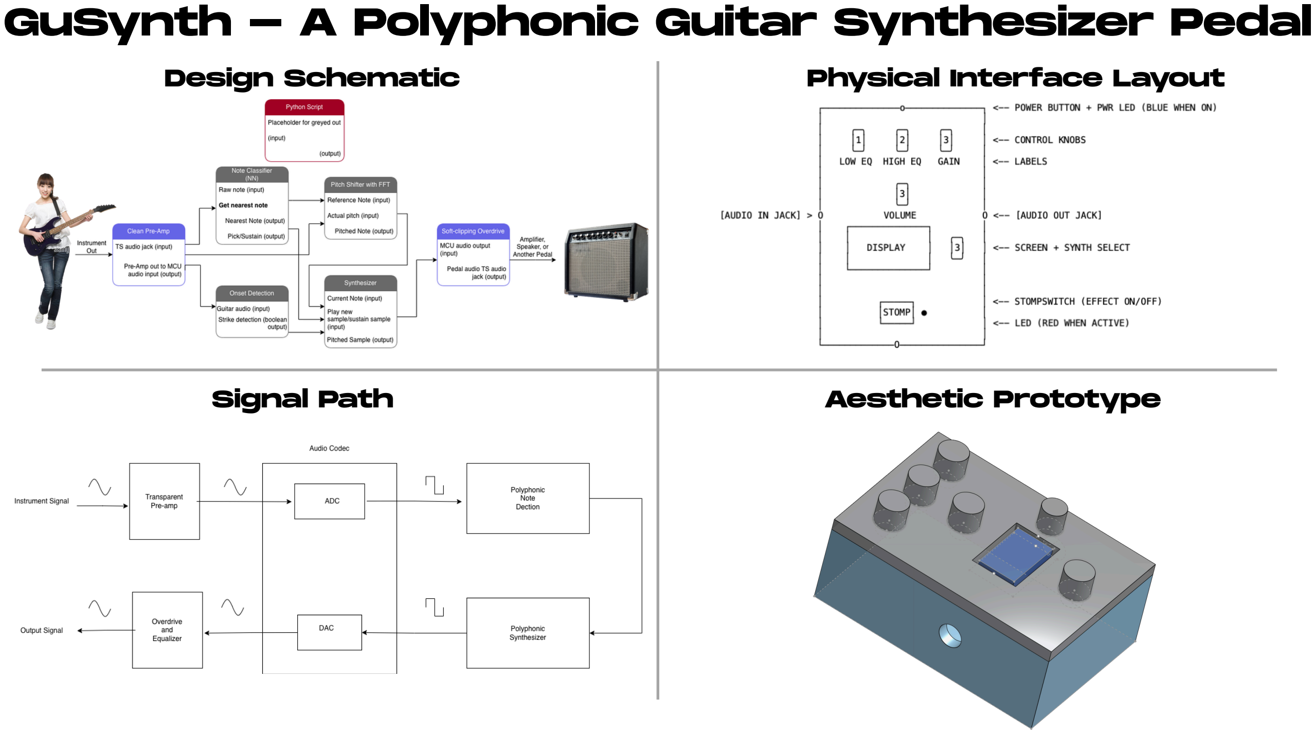
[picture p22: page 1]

Design Schematic

Aesthetic Prototype

Physical Interface Layout

Signal Path

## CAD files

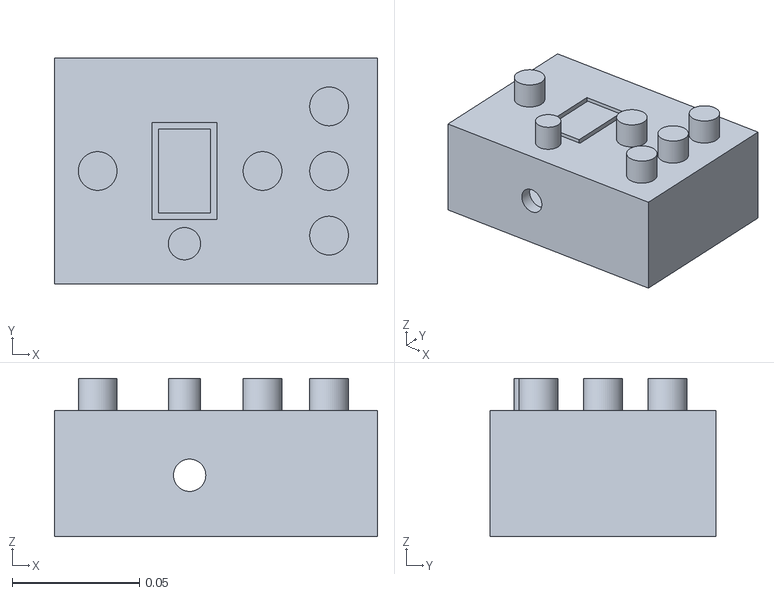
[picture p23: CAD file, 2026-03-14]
Documentation/aesthetic_prototype/PedalBoxAestheticPrototypeCAD.stl
0.127 x 0.0889 x 0.0622

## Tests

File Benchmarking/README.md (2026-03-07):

# Benchmarking

## Overview
This directory contains the strategy and code for benchmarking the Daisy Seed. The benchmarks will test multiple effects, each requiring a different computational demand. Different block sizes will be tested for each effect.

For each effect + block size, the min, max, and avg CPU load in the callback will be measured. The CPU load is the ratio between time spent in the callback by the maximum time available per block. As the audio callback must finish processing a block before the next set of samples are ready to be processed, there is a hard deadline for the processing time of the callback. This test determines if a given effect + block size is able to process an entire of samples before the next samples are ready. 

Estimating the CPU load for an effect is given by:

- $f_s$ : Sample rate
- $t_{per\ sample}$ : Processing time per sample
- $t_{overhead}$ : Callback overhead
- $N$: Number of samples (block size)

$$
CPU\ Load \approx f_s \cdot t_{per\ sample} \ + \ \frac{f_s \cdot t_{overhead}}{N}
$$

From this model, we can see that there is a fixed cost as block size increases ($f_s \cdot t_{per\ sample}$) for an effect. The right side of the equation tells us how block size scales the CPU load. As the block size increases, the CPU load decreases. However, this would increase latency. 

Simple effects have a low fixed cost because ($t_{per sample}$) is low. For increasingly complex effects, this cost is greater. Therefore, for a given CPU load, simpler effects can have a smaller block size than more computationally expensive effects. However, higher block sizes results in higher latency, so we must find an optimal block size that preserves the target latency while still being able to fully process all samples through the effect. 

After all tests have been run and data has been collected, we should have a good idea on the maximum complexity of an effect such that the latency is in an acceptable range and no audio errors occur.

## Effects
The effects were mostly sourced from *DaisyExamples* with slight modifications.

- Passthrough - Baseline
- Simple 
    - Distortion
    - Bitcrush
- Medium
    - Delay
    - Chorus
- Complex
    - Reverb
    - PitchShifter

## Block Sizes
- 16
- 32
- 48
- 64
- 96
- 128
- 256

Note that the max block size supported by the Daisy seed is 256.

## Experiment Strategy
The mentioned block sizes will be tested for each effect. The sample rate across all experiments is *48 kHz*. Each effect processes the same input in its *process_audio()* method, a 220 Hz since wave with an amplitude of 0.4. Note that this signal is generated within the audio callback function, which differs from how the input is handled in the finished pedal. For the finished pedal, the MCU will process an instrument's input via *I2S*, then send it to the audio callback for processing. However, the *Passthrough* experiment only shows a maximum of approximately 2% CPU Load across all block sizes, so the extra processing load is minimal. Regardless, the callback needs to leave some headroom (max $\approx$ 70-80%) to protect against latency spikes so the MCU can still process the buffer in time before the next samples are ready. Essentially, generating input inside the callback is justified because we will cap CPU load at a specific point and can subtract out the minimal computation the generation introduces. The *CPULoadMeter cpu_load* object calculates the min, max, and avg CPU load between the object's *OnBlockStart()* and *OnBlockEnd()* methods. These metrics are tracked every second for five seconds before being printed, reset and looped again. The benchmark also processes ADC input from one of the potentiometers, simulating a musician tuning their effect to get their desired output sound. Each experiment will track the CPU load metrics in a spreadsheet. 

## Results
[Results Spreadsheet](https://docs.google.com/spreadsheets/d/1QgfL2nDbECkWdAaCYBFUneOOQhCu9Kp85AZZbPZRD8g/edit?usp=sharing)

From the results, we can see the effects did not stress the CPU much; the highest maximum CPU load was approximately 14%. There are some trends observed however. For all effects, increasing block size reduced max CPU load to a very small degree (1%). As the CPU did not undergo heavy computation, we still would like to have an idea of the limits of the Daisy Seed. We plan to stress-test the MCU with matrix multiplication. Matrix multiplication is a particularly relevant benchmark because it is computationally demanding and it is used heavily in neural networks, which we are implementing for note/chord detection. We will test different matrix/block sizes and different matrix multiplication algorithms (differing by optimization level).

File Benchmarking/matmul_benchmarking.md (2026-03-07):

# Matrix Multiplication Benchmarking

## Overview
When benchmarking audio effects, the effects themselves did not introduce substantial computational load on the CPU. To better understand the limits of the Daisy Seed's MCU, we decided it was viable to stress-test the MCU with matrix multiplication. Matrix multiplication is a very computationally demanding operation, stressing arithmetic throughput and memory bandwidth. It is an $O(n^3)$ operation, scaling poorly as $n$ (largest matrix dimension) increases. Additionally, matrix multiplication is a particularly suitable experiment to run in since we plan to run neural network inference on the MCU. Neural networks compute many matrix multiplications in a single forward pass, so it is imperative we know matrix multiplication throughput. 

As outlined in the effects benchmarking, the audio callback block size is proportional to the maximum time available in the audio callback. As block size increases, the amount of time we can spend in the callback also increases. A standard method to estimate throughput is by calculating the amount of floating point operations per block (FLOPs/block). In matrix multiplication, for each element of the resulting matrix of height and width *N*, the dot product is computed between a length *N* row vector and length *N* column vector. This results in $2N^3$ FLOPs (multiply + add is two FLOPs) per matrix multiplication.

## Experiment Strategy
Three matrix classes are implemented to not only stress-test the MCU, but also to discover potential optimizations specific to the MCU. The first class stores the data of the matrix as a two-dimensional array. The second class stores the data as a contiguous 1D array. Finally, the third class is a thin wrapper over the *CMSIS-DSP arm_matrix_instance_f32* struct. 

The first class implements the standard mat mul algorithm, a better cache-optimized design, and a tiled approach. The second class implements the same algorithms as the first, but also includes two row pointer caching (simpler inner loop from reloacted address calculations) algorithms. The first row pointer caching algorithm iterates over indices *i-k-j* (cache-aware ordering), while the second one iterates over *i-j-k* (standard ordering). Finally, the third class implements its mat mul as a thin wrapper over the optimized *CMSIS-DSP arm_mat_mult_f32()* function. 

In the audio callback, a mat mul algorithm is repeatedly called. Intially, the algorithm is only run once, but the amount of iterations is increased if the measured CPU load is less than 100%. Once the CPU load is in the range of 90%-100%, CPU load metrics cannot be printed as the matrix multiplications take up virtually all of the available processing time in the callback. When this occurs, the amount of repeated mat muls is at the maximum for the particular block size and is logged in a spreadsheet. From here, the maximum *kFLOPs/block* is calculated with this equation:

$$
kFLOPs/block_{max} = \frac{num\_repeats*(2 * N^3)}{1000}
$$

where *N* is 16, the length of the rows and columns of the three matrices. Note that 16 was chosen because 32 was too large of a matrix for the MCU to finish computation in ~0.167 ms (8 block size). 

For a given algorithm and block size combination, *kFLOPs/block* tells us the maximum FLOPs per callback time. If we need a process to run in a specific time frame, this information gives a a rough estimate of the computational throughput needed to achieve this goal. For example, these calculations can come in handy when we are optimizing neural network inference to run within a specific time budget, say about 5 ms. A block size of 256 runs in ~5.3 ms, so the maximum inference FLOPs should be similar to the experiments with a 256 block size. 

The code is compiled with -O3, -DARM_MATH_CM7, -DUSE_ARM_MATH, and -DARM_MATH_LOOPUNROLL compiler flags.

## Results
[Results Spreadsheet](https://docs.google.com/spreadsheets/d/1QgfL2nDbECkWdAaCYBFUneOOQhCu9Kp85AZZbPZRD8g/edit?usp=sharing)

Interestingly, known matrix optimizations for more "mainstream "(laptops and desktops) CPUs result in worse performance. The *Cache Locality* algorithms (2D and 1D implementations) often result in peformance increases for larger matrix sizes and consumer-grade CPUs. It reorders the triple-loop indices, going from *i-j-k* to *i-k-j*. This provides better cache locality for the second matrix involved in this operation (contiguous access in the inner loop for matrix b). For larger matrices, iteration across different rows of a matrix usually means frequent cache misses and reorder solves this problem. However, since the matrix size is very small (16), elements from different rows may already be present in the cache. Furthermore, the *i-j-k* version accumulates into a local sum (in a register) once per element of the resulting matrix and writes directly to it once. However, the *i-k-j* version must update each element of the resulting matrix per inner loop iteration, resulting in a read-modify-write 16 times per element.

The CMSIS-DSP implementation was clearly the fastest and most performant implementation. If code size is not an issue, the CMSIS-DSP implementations should be used if performance-critical code is necessary.

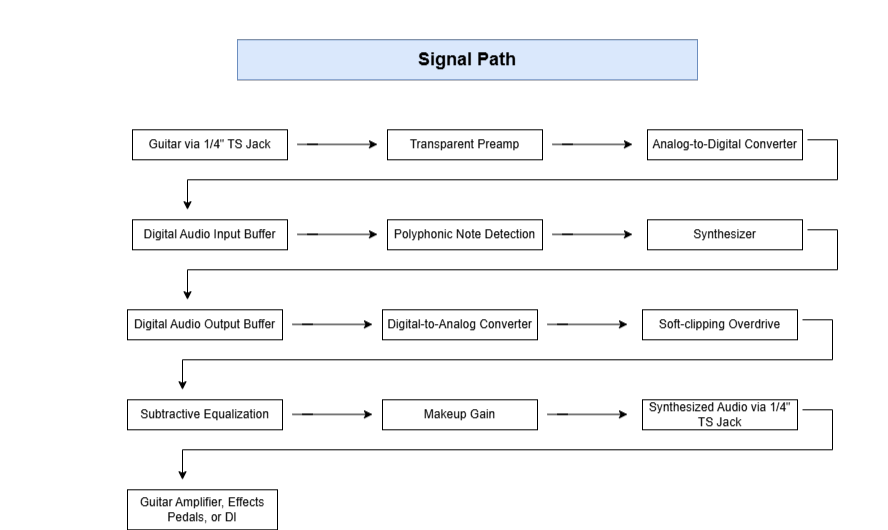
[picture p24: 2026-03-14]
special_effects/test_files/Downloads/LUTPolyphonic.drawio pain2.PNG

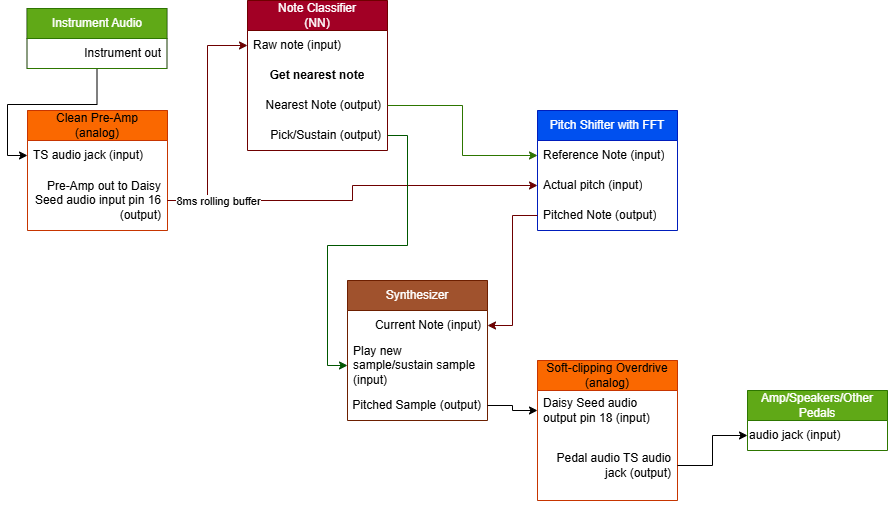
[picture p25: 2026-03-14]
special_effects/test_files/Downloads/LUTPolyphonic.drawio pain.PNG

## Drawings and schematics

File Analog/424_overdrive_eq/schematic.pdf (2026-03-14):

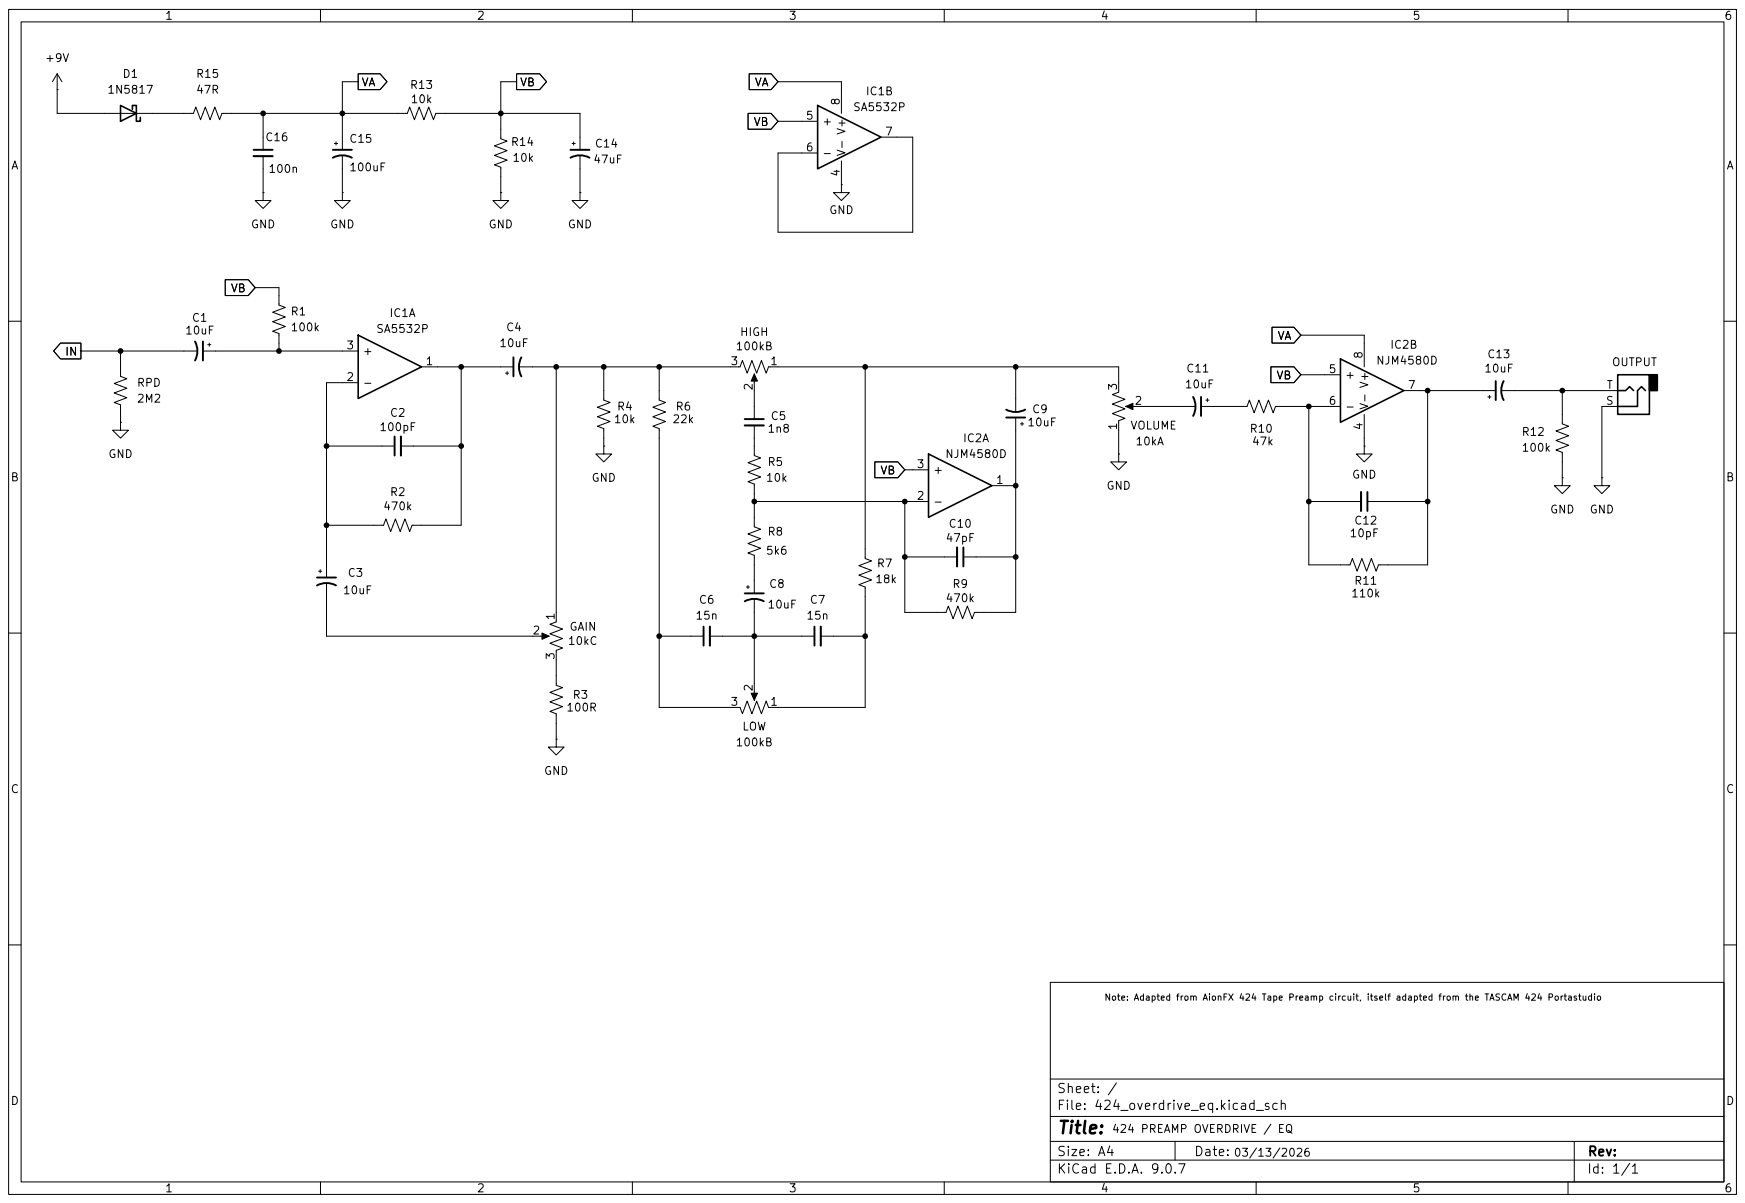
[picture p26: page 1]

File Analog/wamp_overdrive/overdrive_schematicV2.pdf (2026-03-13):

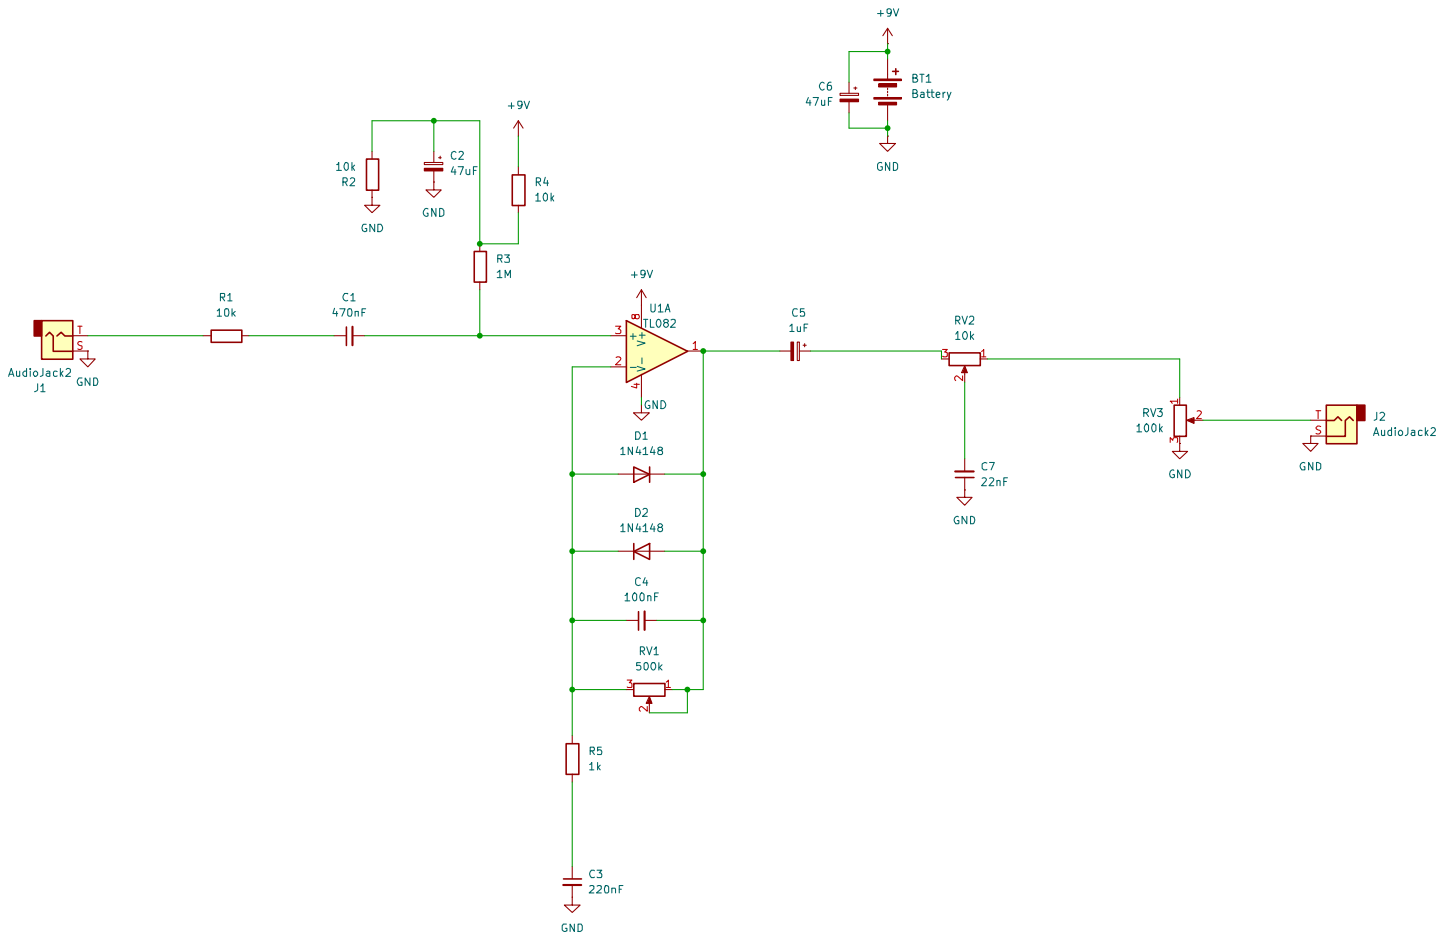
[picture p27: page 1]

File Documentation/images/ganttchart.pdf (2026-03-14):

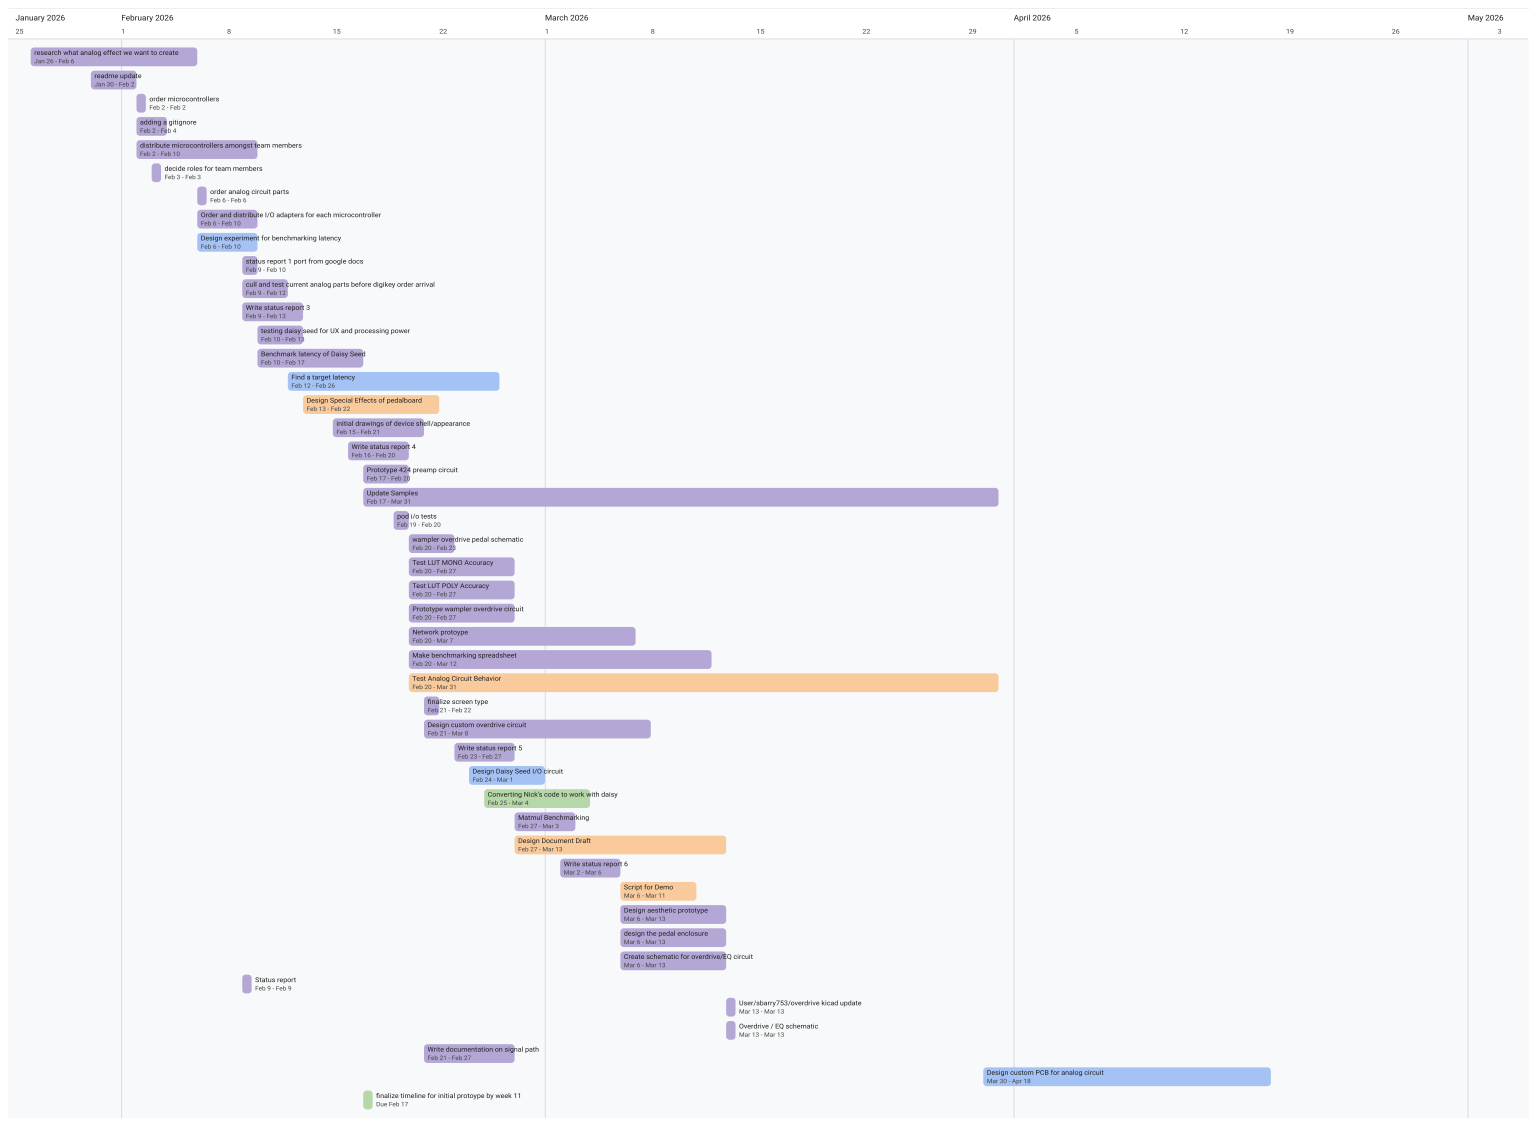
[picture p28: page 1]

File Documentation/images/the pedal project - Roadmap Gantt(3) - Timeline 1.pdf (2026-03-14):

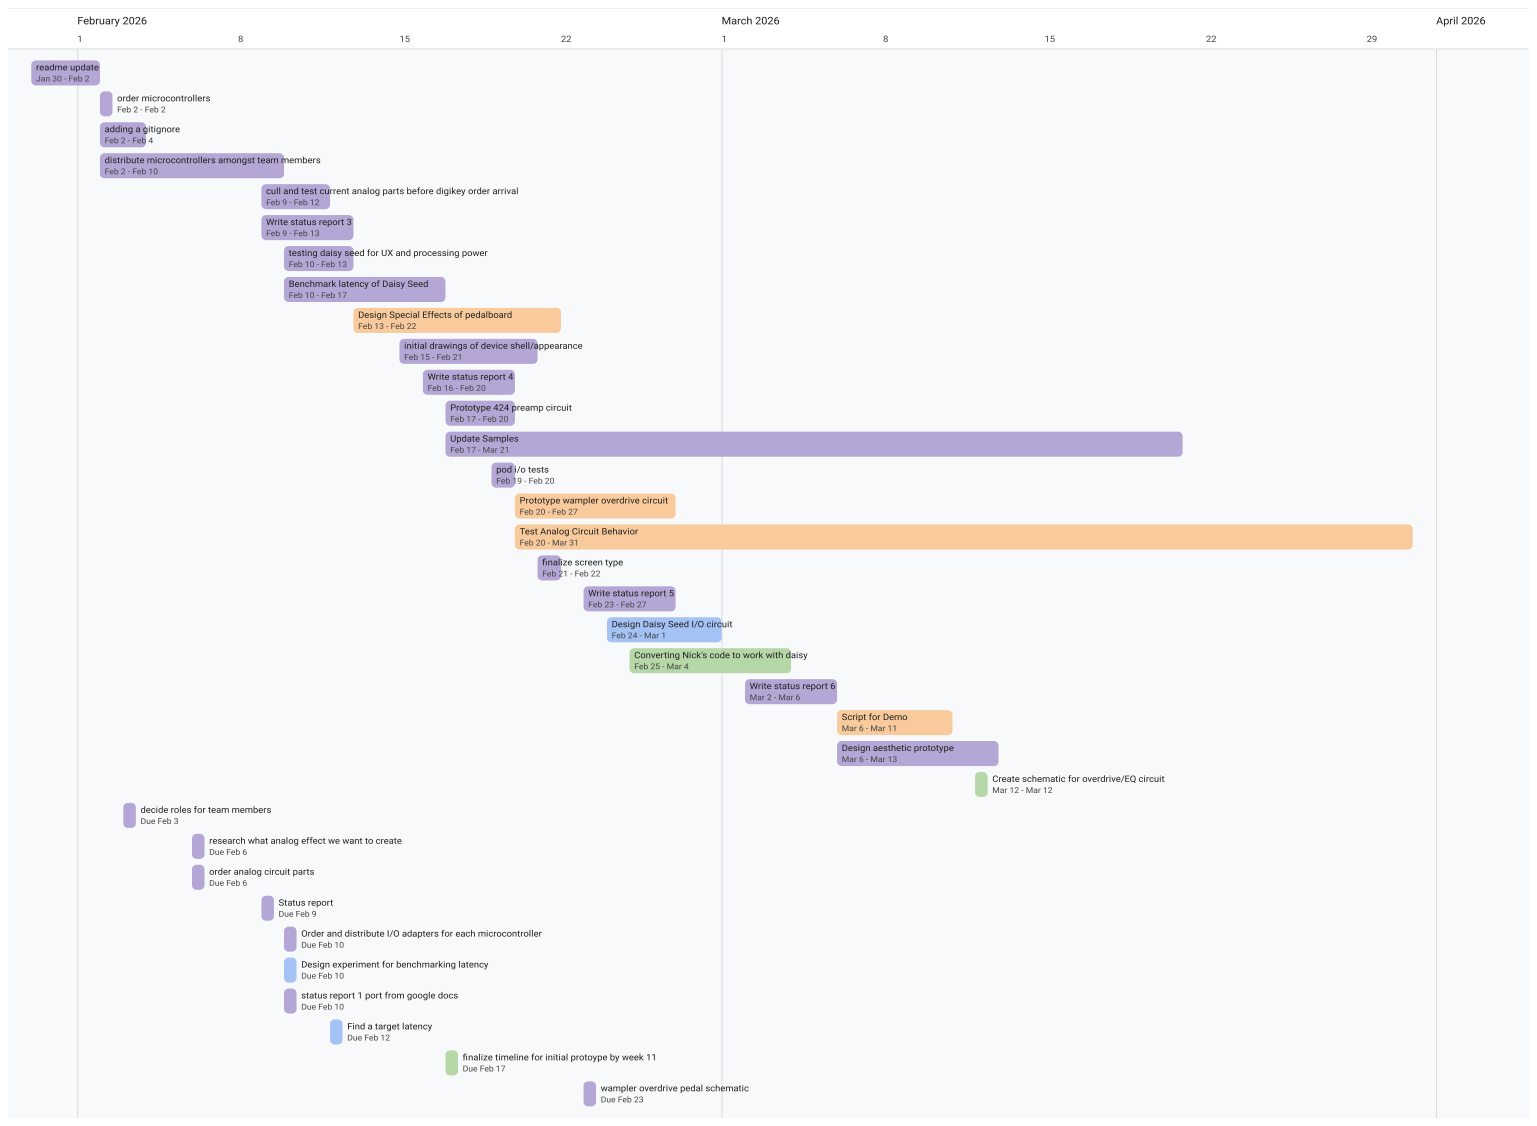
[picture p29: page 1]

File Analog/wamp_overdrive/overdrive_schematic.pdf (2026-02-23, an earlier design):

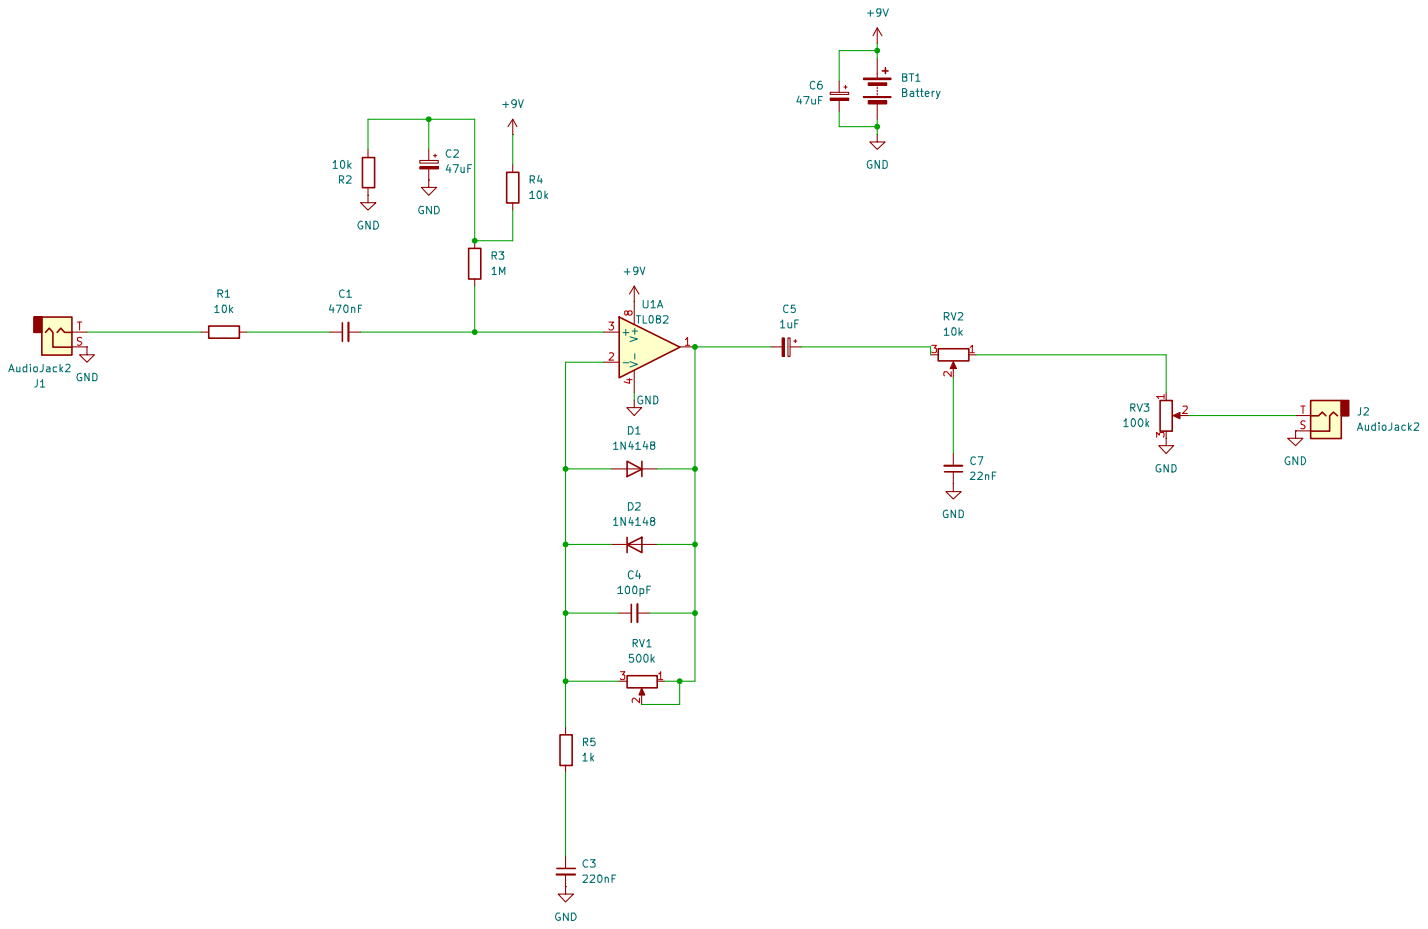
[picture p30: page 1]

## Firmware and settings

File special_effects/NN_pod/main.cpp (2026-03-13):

/**
 * onsetnet_pod.cpp  — v6
 *
 * Architecture:
 *   - 8ms rolling audio window, processed every 8ms (one audio block)
 *   - NN runs on the window → top-K note candidates
 *   - Goertzel runs on the SAME window, guided by NN top-K → picks best pitch
 *   - Voicing gate (RMS dBFS) determines if audio is present
 *   - Note is ON whenever: voiced AND NN confident (no pick detector required)
 *   - Pick detector only used to detect NEW note onset (pitch change)
 *   - Grace window holds note on after confidence drops
 *
 * Knob 1 = synth gain
 * Knob 2 = grace time (0–500ms)
 * Button 1 = cycle waveform (sine/square/saw)
 * Button 2 = mute
 *
 * LEDs:
 *   LED1 GREEN  = note active, NN confident
 *   LED1 RED    = note in grace (holding on after confidence dropped)
 *   LED2 BLUE   = voiced (signal present)
 *   LED2 WHITE  = note just changed (brief flash)
 */

#include "daisy_pod.h"
#include "daisysp.h"
#include "onset_weights.h"
#include <cmath>
#include <cstring>

using namespace daisy;
using namespace daisysp;

#define NOTE_HEAD_OUT 50

// ---------------------------------------------------------------------------
// Config
// ---------------------------------------------------------------------------
static constexpr int   SR              = ONSET_SR;       // 48000
static constexpr int   kWinSamp        = ONSET_WINDOW;   // 384 = 8ms
static constexpr float kHopMs          = 8.0f;           // must match block size
static constexpr int   kTopK           = 3;
static constexpr float kNnOn           = 0.35f;   // enter note if confidence >= this
static constexpr float kNnOff          = 0.25f;   // exit note if confidence < this
static constexpr float kVoicedDbOn     = -75.0f;  // voiced if dBFS >= this
static constexpr float kVoicedDbOff    = -85.0f;  // unvoiced if dBFS <= this
static constexpr float kDefaultGraceMs = 10.0f;
static constexpr float kMinNoteMs      = 0.0f;
static constexpr float kFreqSmooth     = 0.7f;
static constexpr float kPreemph        = 0.10f;
static constexpr float kFftCents       = 80.0f;   // search window ±80 cents
static constexpr float kFftMinHz       = 70.0f;
static constexpr float kSynthAttackMs  = 4.0f;
static constexpr float kSynthReleaseMs = 150.0f;

// ---------------------------------------------------------------------------
// Hardware
// ---------------------------------------------------------------------------
static DaisyPod hw;

// ---------------------------------------------------------------------------
// Synth
// ---------------------------------------------------------------------------
enum Wave { SINE=0, SQUARE, SAW, N_WAVES };

struct Synth {
    int sr; Wave wave;
    float ph, freq, gain, env, tgt, sup, sdn;

    void init(int _sr, float att_ms, float rel_ms) {
        sr=_sr; wave=SINE; ph=0; freq=440; gain=0.5f; env=0; tgt=0;
        int as = (int)(att_ms*1e-3f*sr); if(as<1)as=1;
        int rs = (int)(rel_ms*1e-3f*sr); if(rs<1)rs=1;
        sup=1.0f/as; sdn=1.0f/rs;
    }
    void set_freq(float f)   { if(f>5.0f) freq=f; }
    void set_active(bool on) { tgt = on ? 1.0f : 0.0f; }

    void render(float* out, int n) {
        const float tw   = 2.0f * (float)M_PI;
        const float step = tw * freq / (float)sr;
        for(int i=0;i<n;i++){
            if(env<tgt){ env+=sup; if(env>tgt)env=tgt; }
            else if(env>tgt){ env-=sdn; if(env<tgt)env=tgt; }
            float s;
            switch(wave){
                case SQUARE: s = ph<(float)M_PI ? 1.0f : -1.0f; break;
                case SAW:    s = ph/(float)M_PI - 1.0f;          break;
                default:     s = sinf(ph);                        break;
            }
            out[i] = s * gain * env;
            ph += step; if(ph >= tw) ph -= tw;
        }
    }
} g_synth;

// ---------------------------------------------------------------------------
// Ring buffer  — written from audio ISR, read from main loop
// ---------------------------------------------------------------------------
static constexpr int kRingSize = SR / 4;  // 250ms
static float g_ring[kRingSize];
static volatile int g_ring_w    = 0;
static volatile int g_ring_fill = 0;

static void ring_get_last(float* out, int n) {
    // safe to call from main loop while ISR writes — worst case one sample glitch
    int w = g_ring_w;
    int start = (w - n + kRingSize) % kRingSize;
    for(int i=0;i<n;i++) out[i] = g_ring[(start+i) % kRingSize];
}

// ---------------------------------------------------------------------------
// Audio callback
// ---------------------------------------------------------------------------
static bool  g_muted = false;
static float g_test_phase = 0.0f;

static void AudioCallback(AudioHandle::InputBuffer  in,
                          AudioHandle::OutputBuffer out,
                          size_t size)
{
    hw.ProcessAllControls();

    if(hw.button1.RisingEdge())
        g_synth.wave = (Wave)((g_synth.wave + 1) % N_WAVES);
    if(hw.button2.RisingEdge()){
        g_muted = !g_muted;
        if(g_muted) g_synth.set_active(false);
    }

    // Knob 1 → gain, floor at 0.3 so it can't accidentally be zero
    float k1 = hw.knob1.Process();
    g_synth.gain = k1 < 0.06f ? 0.3f : k1 * 0.7f;

    // Push mono input into ring
    int w = g_ring_w;
    for(size_t i=0;i<size;i++){
        g_ring[w] = (in[0][i] + in[1][i]) * 0.5f;
        if(++w >= kRingSize) w = 0;
    }
    g_ring_w    = w;
    g_ring_fill += (int)size;
    if(g_ring_fill > kRingSize) g_ring_fill = kRingSize;

    // Render synth to output
    float buf[kWinSamp];
    g_synth.render(buf, (int)size);
    for(size_t i=0;i<size;i++){
        float s = g_muted ? 0.0f : buf[i];
        out[0][i] = s;
        out[1][i] = s;
    }
}

// ---------------------------------------------------------------------------
// DSP helpers
// ---------------------------------------------------------------------------
static float calc_rms(const float* x, int n){
    float s=1e-12f;
    for(int i=0;i<n;i++) s+=x[i]*x[i];
    return sqrtf(s/(float)n);
}
static float calc_dbfs(float r){ return 20.0f*log10f(r<1e-12f?1e-12f:r); }

static void do_preemph(float* y, const float* x, int n, float a){
    y[0]=x[0];
    for(int i=1;i<n;i++) y[i]=x[i]-a*x[i-1];
}

static void rms_norm(float* y, const float* x, int n){
    float r=calc_rms(x,n);
    if(r<1e-4f){ memset(y,0,n*sizeof(float)); return; }
    float inv=1.0f/r;
    for(int i=0;i<n;i++) y[i]=x[i]*inv;
}

// ---------------------------------------------------------------------------
// Goertzel pitch search
// Evaluates power at f + first two harmonics
// ---------------------------------------------------------------------------
static float goertzel_power(const float* x, int n, float f){
    float w     = 2.0f*(float)M_PI*f/(float)SR;
    float coeff = 2.0f*cosf(w);
    float s0=0,s1=0,s2=0;
    for(int i=0;i<n;i++){ s0=x[i]+coeff*s1-s2; s2=s1; s1=s0; }
    return s1*s1 + s2*s2 - coeff*s1*s2;
}

static float harmonic_power(const float* x, int n, float f){
    float p = goertzel_power(x, n, f);
    if(f*2.0f < SR*0.48f) p += 0.55f * goertzel_power(x, n, f*2.0f);
    if(f*3.0f < SR*0.48f) p += 0.35f * goertzel_power(x, n, f*3.0f);
    if(f*4.0f < SR*0.48f) p += 0.20f * goertzel_power(x, n, f*4.0f);
    return p;
}

// Search ±cents around centre_hz, nsteps points
static float refine_hz(const float* x, int n, float centre_hz, float cents,
                        int nsteps=16){
    float ratio = powf(2.0f, cents/1200.0f);
    float lo = centre_hz / ratio;
    float hi = centre_hz * ratio;
    if(lo < kFftMinHz) lo = kFftMinHz;
    float bp=-1.0f, bh=centre_hz;
    for(int s=0;s<=nsteps;s++){
        float f = lo + (hi-lo)*(float)s/(float)nsteps;
        float p = harmonic_power(x, n, f);
        if(p > bp){ bp=p; bh=f; }
    }
    return bh;
}

// Given top-K candidates, run Goertzel on each and return the best
// Returns index into candidates array (not midi index)
static int best_candidate(const float* x, int n,
                           const float* cand_hz, const float* cand_conf,
                           int k, float* best_hz_out){
    float bp = -1.0f;
    int   bi = 0;
    float bh = cand_hz[0];
    for(int i=0;i<k;i++){
        if(cand_hz[i] < kFftMinHz) continue;
        float p = harmonic_power(x, n, cand_hz[i]);
        // weight by NN confidence too
        float score = p * (0.6f + 0.4f * cand_conf[i]);
        if(score > bp){ bp=score; bi=i; bh=cand_hz[i]; }
    }
    // refine around winner
    *best_hz_out = refine_hz(x, n, bh, kFftCents);
    return bi;
}

// ---------------------------------------------------------------------------
// MIDI vocab
// ---------------------------------------------------------------------------
static float g_midi_vocab[NOTE_HEAD_OUT];
static inline float midi_to_hz(float m){ return 440.0f*powf(2.0f,(m-69.0f)/12.0f); }
static inline float hz_to_midi(float f){ return 69.0f+12.0f*log2f(f>1e-9f?f/440.0f:1e-9f); }

static int pitch_name_to_midi(const char* s){
    int n;
    switch(s[0]){
        case 'C':n=0;break; case 'D':n=2;break; case 'E':n=4;break;
        case 'F':n=5;break; case 'G':n=7;break; case 'A':n=9;break;
        case 'B':n=11;break; default:n=0;
    }
    int i=1;
    if(s[i]=='#'){ n++; i++; }
    return ((s[i]-'0')+1)*12 + n;
}

static void build_midi_vocab(){
    for(int i=0;i<ONSET_NOTE_VOCAB_SIZE;i++)
        g_midi_vocab[i] = (float)pitch_name_to_midi(onset_pitch_names[i]);
    if(NOTE_HEAD_OUT > ONSET_NOTE_VOCAB_SIZE)
        g_midi_vocab[NOTE_HEAD_OUT-1] = 0.0f;  // silence class
}

// ---------------------------------------------------------------------------
// OnsetNet forward pass
// ---------------------------------------------------------------------------
static constexpr int kT0=192, kT1=96, kT2=48;
static float g_a0[48*kT0], g_a1[96*kT1], g_a2[96*kT2], g_z[ONSET_WIDTH];
static float g_win[kWinSamp], g_pe[kWinSamp], g_nn_in[kWinSamp];

static void conv_bn_relu(
    const float* x,  int c_in,  int T_in,
    float*       out, int c_out, int T_out,
    const float* W,
    const float* bnw, const float* bnb,
    const float* bnm, const float* bnv,
    int K, int stride, int pad)
{
    for(int co=0;co<c_out;co++){
        const float* Wco = W + co*c_in*K;
        float*       o   = out + co*T_out;
        for(int t=0;t<T_out;t++){
            float acc=0.0f;
            int t0 = t*stride - pad;
            for(int ci=0;ci<c_in;ci++){
                const float* xci = x   + ci*T_in;
                const float* Wci = Wco + ci*K;
                for(int k=0;k<K;k++){
                    int ti = t0+k;
                    if((unsigned)ti < (unsigned)T_in) acc += xci[ti]*Wci[k];
                }
            }
            float bn = (acc-bnm[co])/sqrtf(bnv[co]+1e-5f)*bnw[co]+bnb[co];
            o[t] = bn>0.0f ? bn : 0.0f;
        }
    }
}

static void softmax_ip(float* a, int n){
    float mx=a[0];
    for(int i=1;i<n;i++) if(a[i]>mx) mx=a[i];
    float s=0;
    for(int i=0;i<n;i++){ a[i]=expf(a[i]-mx); s+=a[i]; }
    float inv=1.0f/(s+1e-12f);
    for(int i=0;i<n;i++) a[i]*=inv;
}

static inline float sigmoid(float x){ return 1.0f/(1.0f+expf(-x)); }

struct NNOut {
    float note_probs[NOTE_HEAD_OUT];
    float pick_score;
    float sus_score;
};

static void nn_forward(NNOut& o){
    conv_bn_relu(g_nn_in,1,kWinSamp, g_a0,48,kT0,
        l0_conv_weight,l0_bn_weight,l0_bn_bias,l0_bn_running_mean,l0_bn_running_var,9,2,4);
    conv_bn_relu(g_a0,48,kT0, g_a1,96,kT1,
        l1_conv_weight,l1_bn_weight,l1_bn_bias,l1_bn_running_mean,l1_bn_running_var,5,2,2);
    conv_bn_relu(g_a1,96,kT1, g_a2,96,kT2,
        l2_conv_weight,l2_bn_weight,l2_bn_bias,l2_bn_running_mean,l2_bn_running_var,5,2,2);

    for(int c=0;c<ONSET_WIDTH;c++){
        float acc=0.0f;
        const float* ch = g_a2+c*kT2;
        for(int t=0;t<kT2;t++) acc+=ch[t];
        g_z[c] = acc/(float)kT2;
    }

    for(int i=0;i<NOTE_HEAD_OUT;i++){
        float acc = note_head_bias[i];
        const float* wi = note_head_weight + i*ONSET_WIDTH;
        for(int j=0;j<ONSET_WIDTH;j++) acc+=wi[j]*g_z[j];
        o.note_probs[i] = acc;
    }
    softmax_ip(o.note_probs, NOTE_HEAD_OUT);

    { float acc=picked_head_bias[0];  for(int j=0;j<ONSET_WIDTH;j++) acc+=picked_head_weight[j]*g_z[j];  o.pick_score=sigmoid(acc); }
    { float acc=sustain_head_bias[0]; for(int j=0;j<ONSET_WIDTH;j++) acc+=sustain_head_weight[j]*g_z[j]; o.sus_score =sigmoid(acc); }
}

static void top_k(const float* p, int n, int k, int* idx){
    bool used[NOTE_HEAD_OUT]={};
    for(int i=0;i<k;i++){
        float best=-1.0f; int bi=0;
        for(int j=0;j<n;j++) if(!used[j]&&p[j]>best){ best=p[j]; bi=j; }
        idx[i]=bi; used[bi]=true;
    }
}

// ---------------------------------------------------------------------------
// Note state machine
//
// Key difference from v5: the synth is ON whenever we are voiced AND confident.
// We do NOT require a pick event to start playing.
// Pick events only reset the grace window (new note onset).
// ---------------------------------------------------------------------------
static NNOut  g_nn_out;
static bool   g_voiced      = false;
static bool   g_note_active = false;
static int    g_note_midi   = -1;
static float  g_note_hz     = 0.0f;
static int    g_grace_left  = 0;
static int    g_min_left    = 0;
static int    g_change_flash= 0;

static void tick_nn(){
    // 1. Get window
    ring_get_last(g_win, kWinSamp);

    // 2. Voicing gate
    float r  = calc_rms(g_win, kWinSamp);
    float db = calc_dbfs(r);
    if(!g_voiced){ if(db >= kVoicedDbOn)  g_voiced=true; }
    else         { if(db <= kVoicedDbOff) g_voiced=false; }

    // 3. Pre-emphasis + RMS normalise for NN
    do_preemph(g_pe, g_win, kWinSamp, kPreemph);
    rms_norm(g_nn_in, g_pe, kWinSamp);

    // 4. NN forward
    nn_forward(g_nn_out);

    // 5. Top-K candidates — skip silence class (index 49)
    int tk[kTopK];
    top_k(g_nn_out.note_probs, NOTE_HEAD_OUT, kTopK, tk);

    // Build candidate hz + conf arrays for Goertzel
    float cand_hz[kTopK], cand_conf[kTopK];
    int   cand_midi_idx[kTopK];
    int   valid_k = 0;
    for(int i=0;i<kTopK;i++){
        int idx = tk[i];
        if(idx >= ONSET_NOTE_VOCAB_SIZE) continue;  // skip silence
        float m = g_midi_vocab[idx];
        if(m < 28.0f || m > 96.0f) continue;        // sanity range
        cand_hz[valid_k]      = midi_to_hz(m);
        cand_conf[valid_k]    = g_nn_out.note_probs[idx];
        cand_midi_idx[valid_k]= idx;
        valid_k++;
    }

    // NN top-1 confidence (ignoring silence)
    float nn_conf = (valid_k > 0) ? cand_conf[0] : 0.0f;

    // 6. Goertzel — find best pitch among NN candidates
    float refined_hz = 0.0f;
    int   winner     = 0;
    if(valid_k > 0 && g_voiced){
        winner = best_candidate(g_nn_in, kWinSamp,
                                cand_hz, cand_conf, valid_k,
                                &refined_hz);
    }

    // 7. Grace frame counts from knob2
    float grace_ms = hw.knob2.Process() * 500.0f + 50.0f;  // 50–550ms
    int grace_f = (int)(grace_ms / kHopMs); if(grace_f<1) grace_f=1;
    int min_f   = (int)(kMinNoteMs / kHopMs); if(min_f<1) min_f=1;

    // 8. Note state machine
    //    Condition to be "playing": voiced AND nn_conf >= kNnOn AND valid pitch
    bool should_play = g_voiced && (nn_conf >= kNnOn) && (refined_hz > kFftMinHz);

    if(should_play){
        int new_midi = (valid_k>0) ? (int)(g_midi_vocab[cand_midi_idx[winner]] + 0.5f) : g_note_midi;

        if(!g_note_active){
            // Start new note
            g_note_active = true;
            g_note_midi   = new_midi;
            g_note_hz     = refined_hz;
            g_grace_left  = grace_f;
            g_min_left    = min_f;
            g_change_flash= 6;
            if(!g_muted){ g_synth.set_freq(g_note_hz); g_synth.set_active(true); }
        } else {
            // Already playing — update pitch smoothly
            // If note changed by more than 1 semitone, snap immediately
            float semitone_diff = fabsf(hz_to_midi(refined_hz) - (float)g_note_midi);
            if(semitone_diff > 1.2f && nn_conf > 0.35f){
                // Note changed
                g_note_midi    = new_midi;
                g_note_hz      = refined_hz;
                g_change_flash = 6;
            } else {
                // Same note — smooth frequency tracking
                g_note_hz = kFreqSmooth * g_note_hz + (1.0f-kFreqSmooth) * refined_hz;
            }
            g_grace_left = grace_f;  // refresh grace while confident
            if(!g_muted) g_synth.set_freq(g_note_hz);
        }
    } else if(g_note_active){
        // Losing confidence — count down grace
        if(g_min_left > 0) g_min_left--;

        if(g_voiced && nn_conf >= kNnOff){
            // Still somewhat confident while voiced — refresh grace
            // (hysteresis: kNnOff < kNnOn)
            g_grace_left = grace_f;
            // Keep tracking pitch even in grace
            if(valid_k > 0 && refined_hz > kFftMinHz)
                g_note_hz = kFreqSmooth * g_note_hz + (1.0f-kFreqSmooth) * refined_hz;
            if(!g_muted) g_synth.set_freq(g_note_hz);
        } else {
            if(g_min_left <= 0) g_grace_left--;
        }

        if(g_grace_left <= 0 && g_min_left <= 0){
            g_note_active = false;
            g_note_midi   = -1;
            g_note_hz     = 0.0f;
            g_synth.set_active(false);
        }
    }

    // 9. LEDs
    bool in_grace = g_note_active && !should_play;
    hw.led1.Set(
        in_grace ? 1.0f : 0.0f,
        (g_note_active && !in_grace) ? 1.0f : 0.0f,
        0.0f
    );
    if(g_change_flash > 0){ g_change_flash--; hw.led2.Set(1,1,1); }
    else hw.led2.Set(0.0f, 0.0f, g_voiced ? 1.0f : 0.0f);
    hw.UpdateLeds();
}

// ---------------------------------------------------------------------------
// main
// ---------------------------------------------------------------------------
int main(){
    hw.Init();
    // Block size = window size so each callback delivers exactly one hop
    hw.SetAudioBlockSize(kWinSamp);
    hw.SetAudioSampleRate(SaiHandle::Config::SampleRate::SAI_48KHZ);

    build_midi_vocab();
    g_synth.init(SR, kSynthAttackMs, kSynthReleaseMs);

    hw.StartAudio(AudioCallback);

    // Brief LED startup flash so you know it booted
    hw.led1.Set(0,1,0); hw.led2.Set(0,1,0); hw.UpdateLeds();
    System::Delay(300);
    hw.led1.Set(0,0,0); hw.led2.Set(0,0,0); hw.UpdateLeds();

    uint32_t last = System::GetNow();
    while(true){
        uint32_t now = System::GetNow();
        // Run one tick per audio block (every 8ms)
        if((int32_t)(now-last) >= (int32_t)kHopMs){
            last = now;
            tick_nn();
        }
    }
}

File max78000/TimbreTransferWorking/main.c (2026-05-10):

/******************************************************************************
 *
 * Copyright (C) 2022-2023 Maxim Integrated Products, Inc. (now owned by 
 * Analog Devices, Inc.),
 * Copyright (C) 2023-2024 Analog Devices, Inc.
 *
 * Licensed under the Apache License, Version 2.0 (the "License");
 * you may not use this file except in compliance with the License.
 * You may obtain a copy of the License at
 *
 *     http://www.apache.org/licenses/LICENSE-2.0
 *
 * Unless required by applicable law or agreed to in writing, software
 * distributed under the License is distributed on an "AS IS" BASIS,
 * WITHOUT WARRANTIES OR CONDITIONS OF ANY KIND, either express or implied.
 * See the License for the specific language governing permissions and
 * limitations under the License.
 *
 ******************************************************************************/

/**
 * @file        main.c
 * @brief       FreeRTOS Example Application.
 */

#include <stdio.h>
#include <stdint.h>
#include <string.h>
#include <stdlib.h>
#include "FreeRTOS.h"
#include "FreeRTOSConfig.h"
#include "portmacro.h"
#include "task.h"
#include "semphr.h"
#include "FreeRTOS_CLI.h"
#include "mxc_device.h"
#include "wut.h"
#include "uart.h"
#include "lp.h"
#include "led.h"
#include "board.h"
#include "mxc.h"
#include "max9867.h"
#include "buffer.h"

/* FreeRTOS+CLI */
//void vRegisterCLICommands(void);

/* Mutual exclusion (mutex) semaphores */
SemaphoreHandle_t xGPIOmutex;

/* Task IDs */
TaskHandle_t cmd_task_id;

/* Enables/disables tick-less mode */
unsigned int disable_tickless = 1;

/* Stringification macros */
#define STRING(x) STRING_(x)
#define STRING_(x) #x

/* Console ISR selection */
#if (CONSOLE_UART == 0)
#define UARTx_IRQHandler UART0_IRQHandler
#define UARTx_IRQn UART0_IRQn
mxc_gpio_cfg_t uart_cts = { MXC_GPIO0, MXC_GPIO_PIN_2, MXC_GPIO_FUNC_IN, MXC_GPIO_PAD_WEAK_PULL_UP,
                            MXC_GPIO_VSSEL_VDDIOH };
mxc_gpio_cfg_t uart_rts = { MXC_GPIO0, MXC_GPIO_PIN_3, MXC_GPIO_FUNC_OUT, MXC_GPIO_PAD_NONE,
                            MXC_GPIO_VSSEL_VDDIOH };
#else
#error "Please update ISR macro for UART CONSOLE_UART"
#endif
mxc_uart_regs_t *ConsoleUART = MXC_UART_GET_UART(CONSOLE_UART);

mxc_gpio_cfg_t uart_cts_isr;

/* Array sizes */
#define CMD_LINE_BUF_SIZE 80
#define OUTPUT_BUF_SIZE 512

void passthrough_task(void* pvParameters);

/* Defined in freertos_tickless.c */
extern void wutHitSnooze(void);

// ADDED: Circular buffer test configuration
#define BUFFER_SIZE 10
#define PRODUCERS 2
#define CONSUMERS 3
#define MAX_PUTS_PER_PRODUCER 10
const char charset[] = "abcdefghijklmnopqrstuvwxyz";
Buffer testBuffer;

// ADDED: Helper function for buffer test
char* random_string(void) 
{
  int length = (rand() % 6) + 3;
  char *str = pvPortMalloc(length + 1);
  if (!str) return NULL;
  
  for (int i = 0; i < length; i++) {
    str[i] = charset[rand() % (sizeof(charset) - 1)];
  }
  str[length] = '\0';
  return str;
}

// ADDED: Producer task
void producer_task(void *arg)
{
  long tid = (long) arg;
  char* str;
  printf("[BUFFER TEST] Producer %ld started\n", tid);

  for (int i = 0; i < MAX_PUTS_PER_PRODUCER; i++) {
    str = random_string();
    if (str) {
      buffer_put(&testBuffer, str);
      printf("[BUFFER TEST] => P%ld: %s\n", tid, str);
    }
    vTaskDelay(pdMS_TO_TICKS(100));
  }

  printf("[BUFFER TEST] Producer %ld finished\n", tid);
  vTaskDelete(NULL);
}

// ADDED: Consumer task
void consumer_task(void *arg)
{
  long tid = (long) arg;
  char* str;
  printf("[BUFFER TEST] Consumer %ld started\n", tid);

  for (int i = 0; i < (PRODUCERS * MAX_PUTS_PER_PRODUCER) / CONSUMERS; i++) {
    str = buffer_get(&testBuffer);
    printf("[BUFFER TEST] <= C%ld: %s\n", tid, str);
    vPortFree(str);
    vTaskDelay(pdMS_TO_TICKS(200));
  }

  printf("[BUFFER TEST] Consumer %ld finished\n", tid);
  vTaskDelete(NULL);
}

/***** Functions *****/

/* =| UART0_IRQHandler |======================================
 *
 * This function overrides the weakly-declared interrupt handler
 *  in system_max326xx.c and is needed for asynchronous UART
 *  calls to work properly
 *
 * ===========================================================
 */
void UARTx_IRQHandler(void)
{
    MXC_UART_AsyncHandler(ConsoleUART);
    wutHitSnooze();
}


#if configUSE_TICKLESS_IDLE
/* =| freertos_permit_tickless |==========================
 *
 * Determine if any hardware activity should prevent
 *  low-power tickless operation.
 *
 * =======================================================
 */
int freertos_permit_tickless(void)
{
    if (disable_tickless == 1) {
        return E_BUSY;
    }

    return MXC_UART_GetActive(ConsoleUART);
}
#endif

/* =| WUT_IRQHandler |==========================
 *
 * Interrupt handler for the wake up timer.
 *
 * =======================================================
 */
void WUT_IRQHandler(void)
{
    MXC_WUT_ClearFlags();
    NVIC_ClearPendingIRQ(WUT_IRQn);
}
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

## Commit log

2026-02-17 Bringing algorithms into main (#32)
    * Experiment as it currently stands
    * LUT Development stage 1
    * Update README.md
    * Update README.md
    * Lut Generator
    This is a successful LUT generatr that you map each sample to its corrospnding note, at which the code will then output a LUT, and then be able to use that LUT to match a note with a different audio 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
2026-02-23 new samples
2026-02-23 made the wampler overdrive pedal schematic in kicad
    [wamp_overdrive.kicad_pcb, wamp_overdrive.kicad_sch]
2026-02-25 restructure+prototype dataset script
2026-02-25 Neural net prototype code phase 1 on 512 training size
2026-03-09 Delete Demo Materials
    i messed up this was supposed to be a directory
2026-03-11 uploading current design schematic
    TA wants 5 bare minimum requirements pushed to git
2026-03-13 New NN + Pitch Detect
    [note_events.csv]
2026-03-13 updated the wampler overdrive pedal schematic
    [wamp_overdrive.kicad_sch]
2026-03-13 updated gitignore and overdrive schematic and added a pdf of the new schematic
2026-03-14 adding aesthetic prototype to Documentation
    [PedalBoxAestheticPrototypeCAD.stl]
2026-03-14 start of 424 schematic; no component values yet
    [424_overdrive_eq.kicad_pcb, 424_overdrive_eq.kicad_sch]
2026-03-14 completed 424 kicad schematic
    [424_overdrive_eq.kicad_sch]
2026-03-14 added notes
    [424_overdrive_eq.kicad_sch]
2026-03-14 424 schematic pdf
2026-03-16 data; di song fragments
2026-03-31 Add README.md for demo materials directory
2026-04-22 reorganized pedal schematics into Analog folder and adding analog weekly report #1
    [424_overdrive_eq.kicad_pcb, 424_overdrive_eq.kicad_sch, wamp_overdrive.kicad_pcb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]
2026-04-28 No auto kicad backups PLEASE
    [preamp.kicad_pcb, preamp.kicad_sch]
2026-04-28 preamp pcb made
    [preamp.kicad_pcb, preamp.kicad_sch]
2026-04-29 eq schematic made and parts assigned
    [eq.kicad_pcb, eq.kicad_sch]
2026-04-29 EQ pcb started and Analog file re-org
    [eq.kicad_pcb, eq.kicad_sch]
2026-04-29 EQ pcb done
    [eq.kicad_pcb, eq.kicad_sch]
2026-04-29 update gitignore for KiCAD
2026-05-05 update gitignore for Eclipse
    [compsus.kicad_pcb, compsus.kicad_sch]
2026-05-05 started compression and sustainer pedal pcb
2026-05-06 Feather audio passthrough with FreeRTOS (#170)
    * audio passes through feather, not using FreeRTOS or anything
    * correction for cli debug command
    * clean up audio passthrough i2c delay code
    * audio passthrough with freeRTOS
    [main.c, max9867.c]
2026-05-11 Python for testing jetson live playback
2026-05-13 put model on max, failing known-answer test
    [cnn.c, main.c]
2026-05-13 fixed known-sample test
2026-05-13 jetson tensorRT
